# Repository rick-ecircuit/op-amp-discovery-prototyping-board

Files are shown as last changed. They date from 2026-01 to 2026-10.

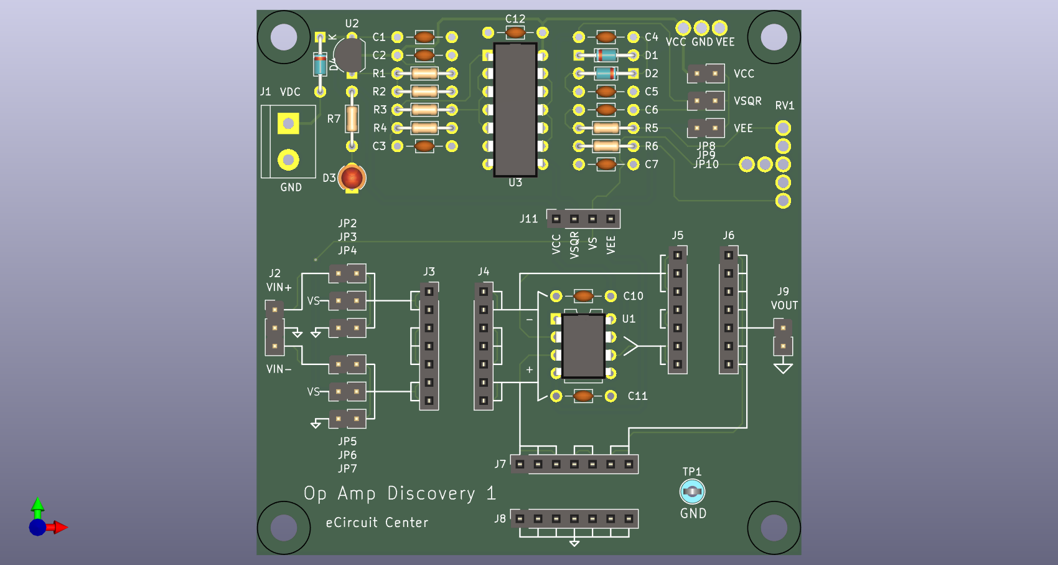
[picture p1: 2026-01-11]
Op_Amp_Discovery_1b/Op_Amp_Discovery_1b.pcb.png

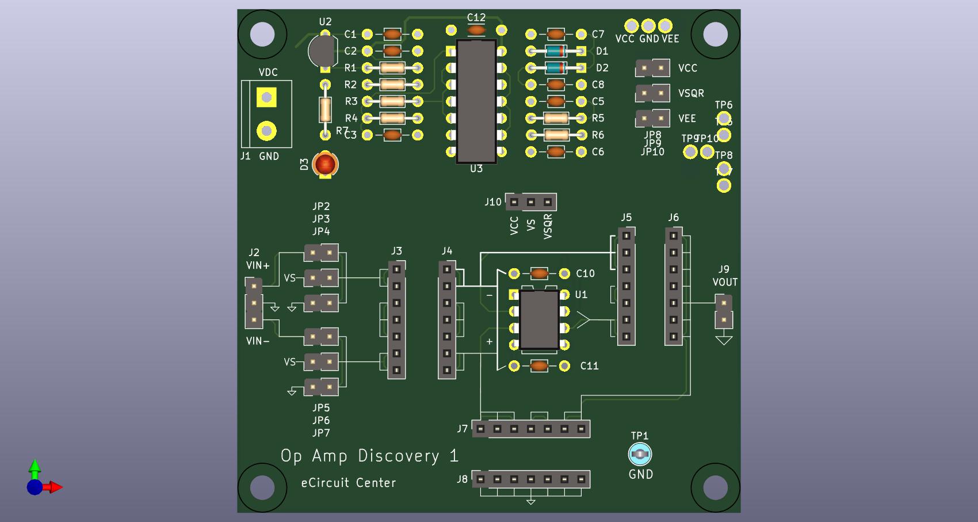
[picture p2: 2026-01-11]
Op_Amp_Discovery_1b/Op_Amp_Discovery_1b.jpg

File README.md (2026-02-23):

# Op Amp Discovery Board
## Fast & Veratile Prototyping and Experimenter Board
The Op Amp Discovery Board allows students, engineers and DIYers to quickly prototype and experiment with a variety of op amp configurations. Get circuits up and running fast! Serves as a Trainer Board as well as an Evaluation Module.

- Easy-to-use hybrid (solderless breadboard + PCB).
- Explore 20+ classic op amp circuits
- Create your own circuits
- Supply Rails & Signal Source Included on-board

Hands-on trainer boosts understanding and intuition!
- Flexible - easily install Rs, Cs or jumpers across any headers.
- Fun problem solving - How-to-build circuit on available component headers?
- Configurable signal - DC, AC, square-wave, level trimpot
- Powered by 9V Battery

Standard breadboards can be frustrating:
- Prone to opens, shorts, intermittent connections
- Confusing, difficult to probe and debug
- Requires expensive, bulky supplies and signal generators

Op Amp Discovery:
- PCB provides solid, versatile connections, power and a signal source.
- Components easily installed on solderless headers.
- Layout arranged like schematic to reinforce learning.
- Minimal cost and PCB space - an affordable & portable learn-anywhere lab.
- Learning possible with a $10 DMM only.

## Users Guide (PDF)
- Quick Start Guide 
- Description, Schematics, BOM
- Proto-Area Schematic, Bonus Sections

## Example Circuits - Guided Learning (PDF)
- Guided examples of classic op amp circuits
- Define It, Design It, Build It, Test & Learn It

## Feedback, Comments, Questions?
Share your thoughts on the [eCircuit Center](https://ecircuitcenter.com/op-amp-discovery/form/feedback1.html) feedback form.

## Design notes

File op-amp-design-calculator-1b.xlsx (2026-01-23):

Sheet: Overview
Overview

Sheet: Non-Inverting
Non-Inverting Amplifier
 |  |  | Enter values
 |  |  | Calc results
Enter circuit
vs | 0.500
R1 | 10000
R2 | 20000
Find gain and output
K | 3.00 | (R1+R2)/R1
vo | 1.500 | vs*K
Find K, R2 given vs, vo, R1
vs | 1.00
vo | 10.00
R1 | 1000
K | 10.00 | Vo/Vs
R2 | 9000 | R1*(K-1)

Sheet: Inverting
Inverting Amplifier
 |  |  | Enter values
 |  |  | Calc results
Enter circuit
vs | 1.000
R1 | 10000
R2 | 20000
Calc gain and output
K | -2.00 | -R2/R1
vo | -2.00 | vs*K
Find R2
vs | 1.000
vo | -10.00
R1 | 1000
K | -10.00 | Vout/Vref
R2 | 10000 | -R1*K

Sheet: Diff Amp
Differential Amplifier
 |  |  | Enter values
 |  |  | Calc results
Enter circuit
R1 | 100000 | ohms
R2 | 100000 | ohms
R3 | 100000 | ohms
R4 | 100000 | ohms
Enter input
Vsp | 5.000 | pos input
Vsn | 4.500 | neg input
Calc Gains Pos and Neg
Kp | 1.000 | R4/(R3+R4) * (R2+R1)/R1
Kn | -1.000 | -R2/R1
Find Output
Vo | 0.500 | (Vsp)*Kp + (Vsn)*Kn

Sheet: Summer
Summing Amplifier
 |  |  | Enter values
 |  |  | Calc results
Enter inputs
vs1 | 5.000 | ohms
R1 | 200000 | ohms
Vs2 | -1.000 | ohms
R2 | 100000 | ohms
Enter feedback
R3 | 100000 | ohms
Calc Gains
K1 | -0.50 | vo/vs1 = -R3/R1
K2 | -1.00 | vo/vs2 = -R3/R2
Calc output due to each input
vo1 | -2.500 | vs1*K1
vo2 | 1.000 | vs2*K2
Sum outputs together
Vo | -1.500 | vo1+vo2

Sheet: Integrator
Integrator
 |  |  | Enter values
 |  |  | Calc results
Enter circuit
Vin | 0.250 | DC input
Δt | 0.000100 | time interval
R1 | 100000
C1 | 1e-10
Find currents in R1,C1
I_R1 | 2.5e-06 | Vin / R1
I_C1 | 2.5e-06 | I_R1
Calc Vout
ΔVout | -2.50 | -1/C1 * I_C1*Δt

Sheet: Differentiator
Differentiator
 |  |  | Enter values
 |  |  | Calc results
Enter input slope
ΔVin | 0.250
Δt | 0.000100
Enter circuit
C1 | 1e-08
R1 | 50000
Find currents in C1,R1
I_C1 | 2.5e-05 | C1*ΔVin/Δt
I_R1 | 2.5e-05 | I_C1 same current as resistor
Calc Vout
Vout | -1.25 | -I_R1*R1
Create Triangle wave from Square wave passed thru Low Pass Filter
Vsqr | 5.00 | amplitude of square wave
fsqr | 5000 | frequency of square wave
Tsqr | 0.000200 | 1/fsqr (period of square wave)
Choose Tau of Low-Pass Filter 5x to 10x longer than Tsqr
Tau | 0.001000 | frequency of square wave
Choose R
R | 1000
Calc C
C | 1e-06 | Tau/R
Calc slope of rising edge "triangle" of filter output
Slope (V/s) | 2500 | Vsqr/2 *1/Tau
Choose time interval
ΔT | 0.000100
Calc voltage change
ΔV | 0.250000 | Slope*ΔT
NOTE: Enter ΔV and ΔT for input slope at top.

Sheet: Sallen-Key LP Fil
Sallen-Key Low-Pass Filter
 |  |  | enter values
 |  |  | calc results
Enter circuit (equal values for R, C and K=1)
R1,2 | 47000
C1,2 | 1e-08
Calculate the cuttoff frequency
fc (-3dB) | 338.6 | 1 / (2 pi R C)
Enter input signal
f (Hz) | 4000.0
Vs | 4.80
Calc approx attenuation of input signal
Katt (ratio) | 11.8 | ≈ f/fc
Katt (dB) | -42.9 | ≈ 2*20*log(f/fc)
vo | 0.034 | ≈ vs*Katt

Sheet: Square Wave Osc
RC Square-Wave Oscilator
 |  |  | enter values
 |  |  | calc results
Enter circuit
R1 | 10000
R2 | 10000
Ro | 47000
Co | 1e-09
Enter output voltage
Vo | 1.80 | LED voltage
Calc feedback ratio
B | 0.500 | Vth = Vo*R1 / (R1+R2)
Find osc frequency and period
fo (Hz) | 9683.396028 | fo = 1 / ( 2*Ro*Co*ln[ (1 - B) /(1 + B) ] )
To (Hz) | 0.0001032695551

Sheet: Wien-Bridge Osc
RC Wien-Bridge Oscilator
 |  |  | enter values
 |  |  | calc results
Enter circuit
R1 | 4700
R2 | 10000
R | 200000 | R3,R4
C | 1e-06 | C3,C4
Calc non-inverting gain: >3 needed for osc
K = vo/vp | 3.13 | k = (R1+R2)/R1
Calc oscillation frequency and period
fo (Hz) | 0.7958 | fo = 1 / (2 pi R C)
To (s) | 1.256637

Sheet: Half-Wave Rect
Precision Rectifier - Inverting Amp
 |  |  | Enter values
 |  |  | Calc results
Enter circuit
vs | 1.000
R1 | 10000
R2 | 20000
Find Vout (for half wave only)
K | -2.00 | -R2/R1
vo | -2.00 | vs*K
Find K, R2 given vs, vo, R1
vs | 1.000
vo | -10.00
R1 | 1000
K | -10.00 | Vout/Vref
R2 | 10000 | -R1*K

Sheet: Cstray
Amplifier with Cstray
 |  |  | Enter values
 |  |  | Calc results
Enter circuit
R1 | 470000
Cstray | 1e-11 | PCB capacitance at U1 neg input
R2 | 470000
CC | 1e-12 | Added compensation Cap
Find time constants of each RC pair
Tau1 | 4.7e-06 | R1*Cstray
Tau2 | 4.7e-07 | R2*CC
Calc CC for matched Tau1 to Tau2
Find CC | 1e-11 | Cstray*R2 / R1
 | Copy this value into CC above.

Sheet: Current Source
Op Amp Current Source
LED Current Drive |  |  | Enter values
 |  |  | Calc results
Enter circuit
Vs | 1.000
Rs | 470
Find Iout
Iout | 0.0021 | Vs/Rs
Enter LED voltage
Vled | 1.800
Calc op amp output voltage
Vu1.out | 2.800 | Vs + Vled

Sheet: Voltage Reg
Voltage Regulator
 |  |  | Enter values
 |  |  | Calc results
Enter circuit
Vs | 1.000
Rload | 1000
Rb | 1000
Enter Q1
Vbe | 0.700
Beta | 100 | current gain Bet = Ic/Ib
Find Vout and Q1 current
Vout | 1.0000 | Vs
Iout = Ie | 0.001000 | Vout/Rload
Ib | 0.000010 | Ie / (Beta+1)
Calc op amp output voltage
Vu1.out | 1.710 | Vout + Vbe + Rb*Ib

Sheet: Remote Sense
Remote Voltage Sense at Rload
 |  |  | Enter values
 |  |  | Calc results
Enter circuit
Vs | 1.000
Rload | 1000
Rwire1 | 100 | resistance of long wire
Rwire2 | 100 | resistance of long wire
Find Iout
Vout | 1.0000 | Vs
Iout | 0.0010 | Vout/Rload
Calc op amp output voltage
Vu1.out | 1.100 | Vout + Iload*Rwire1
NOTE: Negligible voltage across Rwire2 because U1 input bias current relatively small.

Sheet: Twin-T Feedback
Amplifier - Twin-T Feedback
 |  |  | Enter values
 |  |  | Calc results
Enter Circuit
vs | 0.250
R1 | 100000
R2 | 100000
R3 | 10000
R4 | 1000 | Choose R3 10x to 100x less than R2
Calc gain from Vout to Va
Katt = Va/Vout | 0.09 | R4/(R3+R4)
Kmult | 11.00 | 1/Katt (effective mutiplier of R2)
Calc overall gain (approx)
K | -11.00 | -R2*Kmult /R1
Vout | 0.02 | vs*K

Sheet: Thermistor Preamp
Thermistor Preamp
 |  |  | Enter values
 |  |  | Calc results
Enter Circuit
Vcc | 5.000
R1 | 10000
R2 | 10000
Rth | 10000 | Thermistor at 25 deg C
R4 | 10000
Enter thermistor tempco (ΔR/ΔT)
Rtempco | -4.0 | %/C
Calc output at 25C
Vo | 0.000 | Vcc*R4/(Rth+R4)*(R2/R1+1) - Vcc*R2/R1
Calc thermistor at 26C
Rth' | 9600 | Rth*(1 - Rtempco/100)
Calc output at 26C
Vo' | 0.102 | Vcc*R4/(Rth'+R4)*(R2/R1+1) - Vcc*R2/R1
Calc sensitivity - Vo change per degree (25 to 26C)
S = ΔVo/ΔT | 0.102 | (Vo' - Vo ) / 1 deg C
Enter voltage change measured after heat/cold applied to thermistor
ΔVo | 1.200
Calc temperature change
ΔT | 11.8 | ΔVo / S

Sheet: Comparator
Comparator with Hysteresis
Non-Inverting |  |  | Enter values
 |  |  | Calc results
Enter circuit |  | Low Battery (1.5V) Indicator
Vcc | 5.000
R1 | 3300
R2 | 1000
Calc threshold at op amp neg input
Vth | 1.16 | Vcc*R2/(R1+R2)
Enter comparator output hi and lo
Vo_HI | 1.80 | LED Voltage
Vo_LO | -1.80
Calc feedback from Vo to at op amp input (vp) with vo_hi and vo_lo
R3 | 4700
R4 | 100000
K3 | 0.045 | R3/(R3+R4)
Vhys_hi | 0.081 | Vo_hi*K3
Vhys_lo | -0.081 | Vo_lo*K3
Calc equivalent thresholds at vs
K4 | 0.955 | R4/(R3+R4)
Vs_hi | 1.302 | (vth + Vhys_hi)/K4
Vs_lo | 1.133 | (vth - Vhys_lo)/K4
Calc hysteresis
Vhys | 0.169 | Vs_hi - Vs_lo

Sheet: I-to-V Converter
I-to-V Converter
Photodiode Preamp |  |  | Enter values
 |  |  | Calc results
Enter circuit
Is | 1e-06 | Current from photodiode D1 (connected reversed biased.)
R2 | 470000
CC | 1e-10 | Capacitance to keep stable
Calc output
Vout | 0.470 | -Is*R2

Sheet: Single-Supply Amp
Single-Supply AC Amplifier
 |  |  | Enter values
 |  |  | Calc results
Enter signal and gain circuit
Vs | 0.500
C1 | 1e-08
R1 | 10000
R2 | 20000
Enter offset circuit
Vcc | 5.000
R3 | 10000
R4 | 10000
Calc Signal Gain
Ksig | -2.0 | -R2/R1
Calc AC signal output
Vo_AC | -1.000 | Vs*Ksig
Calc DC offset at output
Vo_DC | 2.500 | Vcc*R4/(R3+R4)
Calc cutoff freq fc of C1, R1 input high-pass filter
fo (Hz) | 1591.549431 | fo = 1 / (2*pi*R*C)

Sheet: Capacitive Load
Driving a Capacitive Load
 |  |  | Enter values
 |  |  | Calc results
NOTE: General rules of thumb below.
Enter load
Cload | 1e-06
Enter op amp params
Rout | 40 | output R
fu | 1000000 | unity-gain freq (GBWP)
Enter Isolation resistor so that pole fp << fu
Riso | 100 | typically 20 to 100 ohms
fp (Hz) | 1136.821022 | fp ≈ 1 / (2*pi*(Rout+Riso)*Cload)
Enter Rf ≈ 100 x Riso
Rf | 10000 | typically 1k to 20k
Adjust Cc so that zero fz ≈ fp
Cc | 1.5e-08
fz (Hz) | 1061.032954 | fz ≈ 1 / (2*pi*Rf*Cf)
NOTE: These are rules of thumb only!
Experimentally vary Cc to for acceptable waveform.

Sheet: Signal Source Divider
Signal Source - R-Divider
 |  |  | Enter values
 |  |  | Calc results
Enter signal
Vsqr | 5.00
Enter and R-divider
R5 | 3000
RV1 | 1000
R6 | 1000
Calc output Vs max and min
Vs_max | 2.000 | Vsqr * (RV1+R6) / (R5 + RV1 + R6)
Vs_max | 1.000 | Vsqr * (R6) / (R5 + RV1 + R6)
Calc Input High-Pass Filter
C6 | 1e-07 | Optional: Short if not used
Rtot | 5000 | R5+RV1+R6
fc (Hz) | 318.3098862 | fc = 1 / (2*pi*Rtot*C6)
Calc output Low-Pass Filter
C7 | 1e-09 | Optional: Open if not used
RV1tap (full cw) | 1200 | R5 || (RV1+R6)
fc (Hz) | 132629.1192 | fc = 1 / (2*pi*RV1tap*C7)

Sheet: Linear Regulator
Linear Regulator
 |  |  | Enter values
 |  |  | Calc results
Enter circuit
Vref | 1.250
R1 | 1000
R2 | 3010
Calc output
Vout | 5.01 | (R1+R2)/R1
Find R2
Vref | 1.250
Vout | 5.00
R1 | 1000
K | 4.00 | Vout/Vref
R2 | 3000 | R1*(K-1)

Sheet: RC Inverter Osc
RC Schmitt Oscillator
 |  |  | enter values
 |  |  | calc results
Enter circuit
R | 200000
C | 1e-09
Vcc | 4.80 | Supply
Enter Schmidt trigger thresholds
Vp | 1.700 | positive switching threshold
Vn | 2.780 | negative switching threshold
Calc hi and lo periods
T_hi | 8.566092002e-05 | R*C*ln[ (Vcc - Vn) / (Vcc - Vp) ]
T_lo | 9.836453533e-05 | R*C*ln[ Vn / Vp ]
Calc total period and freq
Ttot | 0.0001840254553 | T_hi + T_lo
fo (Hz) | 5434.030842

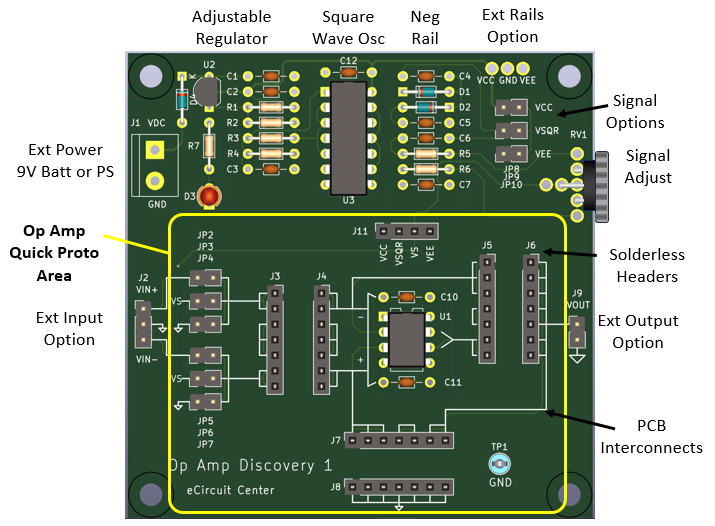
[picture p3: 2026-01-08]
Op-Amp-Discovery-PCB.PNG

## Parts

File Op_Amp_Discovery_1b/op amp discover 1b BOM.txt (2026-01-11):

Reference	Value	Datasheet	Footprint	Qty	DNP
C1,C2	1uF	~	A_Custom_Library:C_Disc_D3.0mm_W1.6mm_P2.50mm_wider_center_dia	2	
C3	1nF	~	A_Custom_Library:C_Disc_D3.0mm_W1.6mm_P2.50mm_wider_center_dia	1	
C4,C5	10uF	~	A_Custom_Library:C_Disc_D3.0mm_W1.6mm_P2.50mm_wider_center_dia	2	
C6,R6	Short	~	A_Custom_Library:C_Disc_D3.0mm_W1.6mm_P2.50mm_wider_center_dia,A_Custom_Library:R_Axial_DIN0204_L3.6mm_D1.6mm_P7.62mm_Horizontal-bigger_hole	2	
C7,R4	Open	~	A_Custom_Library:C_Disc_D3.0mm_W1.6mm_P2.50mm_wider_center_dia,A_Custom_Library:R_Axial_DIN0204_L3.6mm_D1.6mm_P7.62mm_Horizontal-bigger_hole	2	
C10,C11,C12	0.1uF	~	A_Custom_Library:C_Disc_D3.0mm_W1.6mm_P2.50mm_wider_center_dia	3	
D1,D2,D4	1N5711	~	A_Custom_Library:D_DO-34_SOD68_P7.62mm_Horizontal	3	
D3	LED	~	LED_THT:LED_D3.0mm	1	
J1	Screw_Terminal_01x02	~	TerminalBlock:TerminalBlock_bornier-2_P5.08mm	1	
J2	Conn_01x03_Pin	~	Connector_PinHeader_2.54mm:PinHeader_1x03_P2.54mm_Vertical	1	
J3,J4,J5,J6,J7,J8	Conn_01x07	~	Connector_PinSocket_2.54mm:PinSocket_1x07_P2.54mm_Vertical	6	
J9	Conn_01x02_Pin	~	Connector_PinHeader_2.54mm:PinHeader_1x02_P2.54mm_Vertical	1	
J11	Conn_01x04	~	Connector_PinSocket_2.54mm:PinSocket_1x04_P2.54mm_Vertical	1	
JP2,JP3,JP4,JP5,JP6,JP7,JP8,JP9,JP10	Jumper_2_Small_Open	~	Connector_PinHeader_2.54mm:PinHeader_1x02_P2.54mm_Vertical	9	
R1,R7	1k	~	A_Custom_Library:R_Axial_DIN0204_L3.6mm_D1.6mm_P7.62mm_Horizontal-bigger_hole	2	
R2	3.01k	~	A_Custom_Library:R_Axial_DIN0204_L3.6mm_D1.6mm_P7.62mm_Horizontal-bigger_hole	1	
R3	200k	~	A_Custom_Library:R_Axial_DIN0204_L3.6mm_D1.6mm_P7.62mm_Horizontal-bigger_hole	1	
R5	3.3k	~	A_Custom_Library:R_Axial_DIN0204_L3.6mm_D1.6mm_P7.62mm_Horizontal-bigger_hole	1	
TP1,TP2,TP3,TP4,TP5,TP6,TP7,TP8,TP9,TP10,TP11	TestPoint	~	A_Custom_Library:TestPoint_THTPad_D2.0mm_Drill1.0mm_bigger,TestPoint:TestPoint_Keystone_5005-5009_Compact	11	
U1	LM741	http://www.ti.com/lit/ds/symlink/lm741.pdf	Package_DIP:DIP-8_W7.62mm	1	
U2	LM317L_TO92	http://www.ti.com/lit/ds/snvs775k/snvs775k.pdf	Package_TO_SOT_THT:TO-92_Inline_Wide	1	
U3	74HC14	http://www.ti.com/lit/gpn/sn74HC14	Package_DIP:DIP-14_W7.62mm	1

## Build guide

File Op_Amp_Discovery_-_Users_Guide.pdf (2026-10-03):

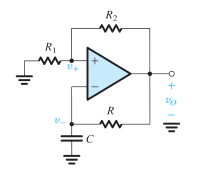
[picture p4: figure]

1 | eCircuit Center | Rev 1c

# Op Amp Discovery

# Fast & Flexible Experimenter and Learning Board

Contents

## 1 Intro

The Op Amp Discovery Board allows students, engineers and DIYers to quickly build and experiment with a variety of op amp configurations. Hands-on learning boosts understanding and intuition!

- Easy-to-use hybrid (solderless breadboard / PCB)
- Explore 20+ classic op amp circuits
- Create your own circuits
- Supply Rails & Signal Source Included on-board

## 2 Fast & Flexible Prototyping

Quickly build and explore many classic op amp circuits with component headers and configurable circuits. Follow self-directed or guided learning.

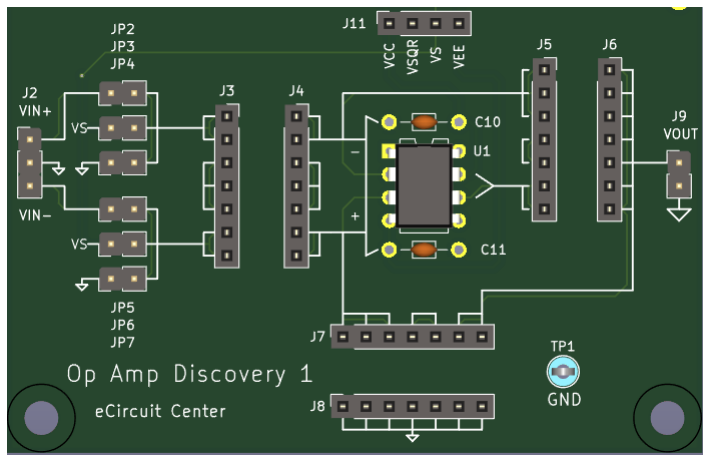
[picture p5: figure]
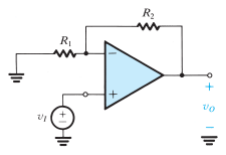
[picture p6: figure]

- Flexible - easily install Rs, Cs or jumpers across any headers.
- Fun problem solving - How-to-build circuit on headers?
- Configurable signal - DC, AC, square-wave, level trimpot

## 3 Problems Solved

Standard breadboards can be frustrating:

- Prone to opens, shorts, intermittent connections
- Confusing, difficult to probe and debug
- Requires expensive, bulky supplies and signal generators

Op Amp Discovery:

- PCB provides solid, versatile connections, power and a signal source.
- Layout arranged like schematic to reinforce learning.
- Minimal cost and PCB space - an affordable & portable learn-anywhere lab.
- Learning possible with a $10 DMM only.

## 4 Overview

The Op Amp Discovery provides essential support circuitry for a stand-alone learning lab. Circuit flexibility allows for custom or more complex setups.

The “Schematic” style of the PCB layout helps build understanding and intuition.

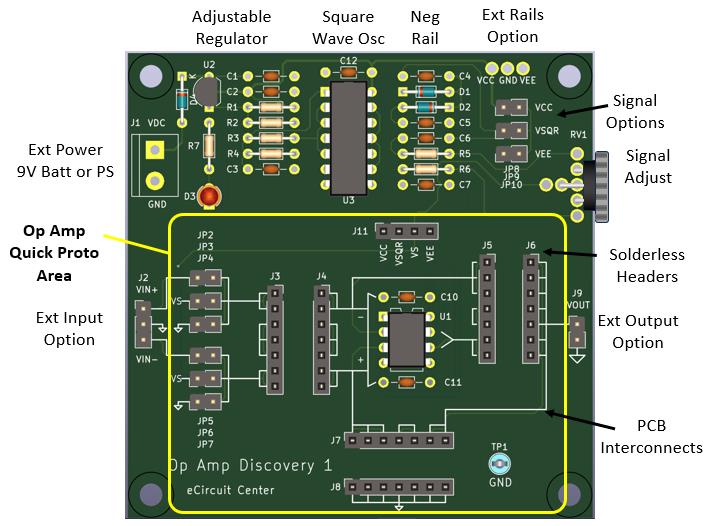
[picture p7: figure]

Overview

- Solderless Headers for easy install of components.
- PCB interconnects for versatile circuit options.
- Op Amp socket for DIP (or SMD on 8-pin header).
- Power from single source (9V battery)

Signal Source

- Scalable Square Wave (0 to 5V)
- Selectable DC or AC coupling.
- Adjustable Amplitude (Trimpot RV1)
- External Input / Outputs (Optional)

Power Rails

- Positive Rail VCC: Adjustable Regulator (5V default)
- Negative Rail VEE: Cap Charge Inverter (-4.5V)
- Solder pads for External Rails option.

## 5 Quick Start Guide

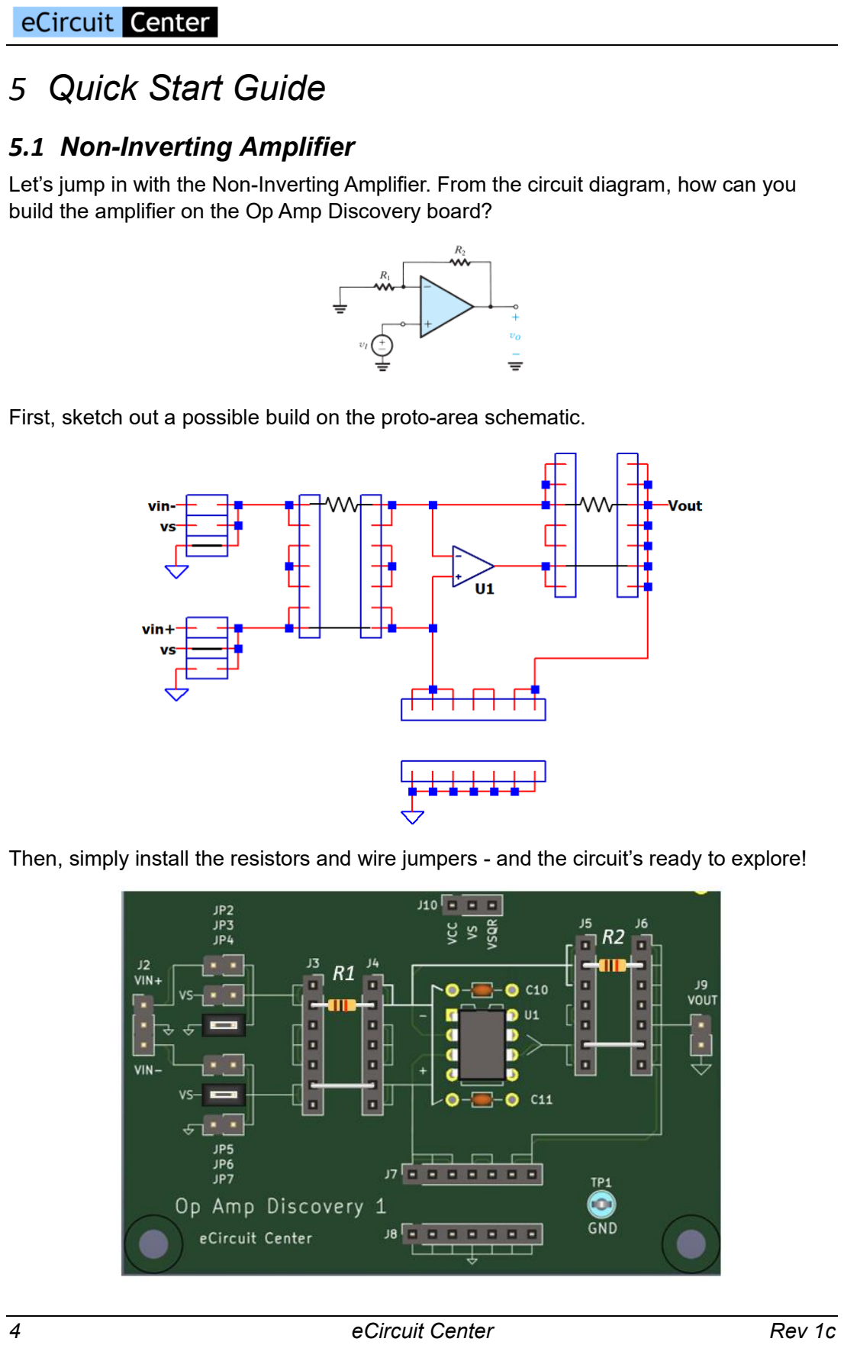
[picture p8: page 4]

### 5.1 Non-Inverting Amplifier

Let’s jump in with the Non-Inverting Amplifier. From the circuit diagram, how can you build the amplifier on the Op Amp Discovery board?

First, sketch out a possible build on the proto-area schematic.

Then, simply install the resistors and wire jumpers - and the circuit’s ready to explore!

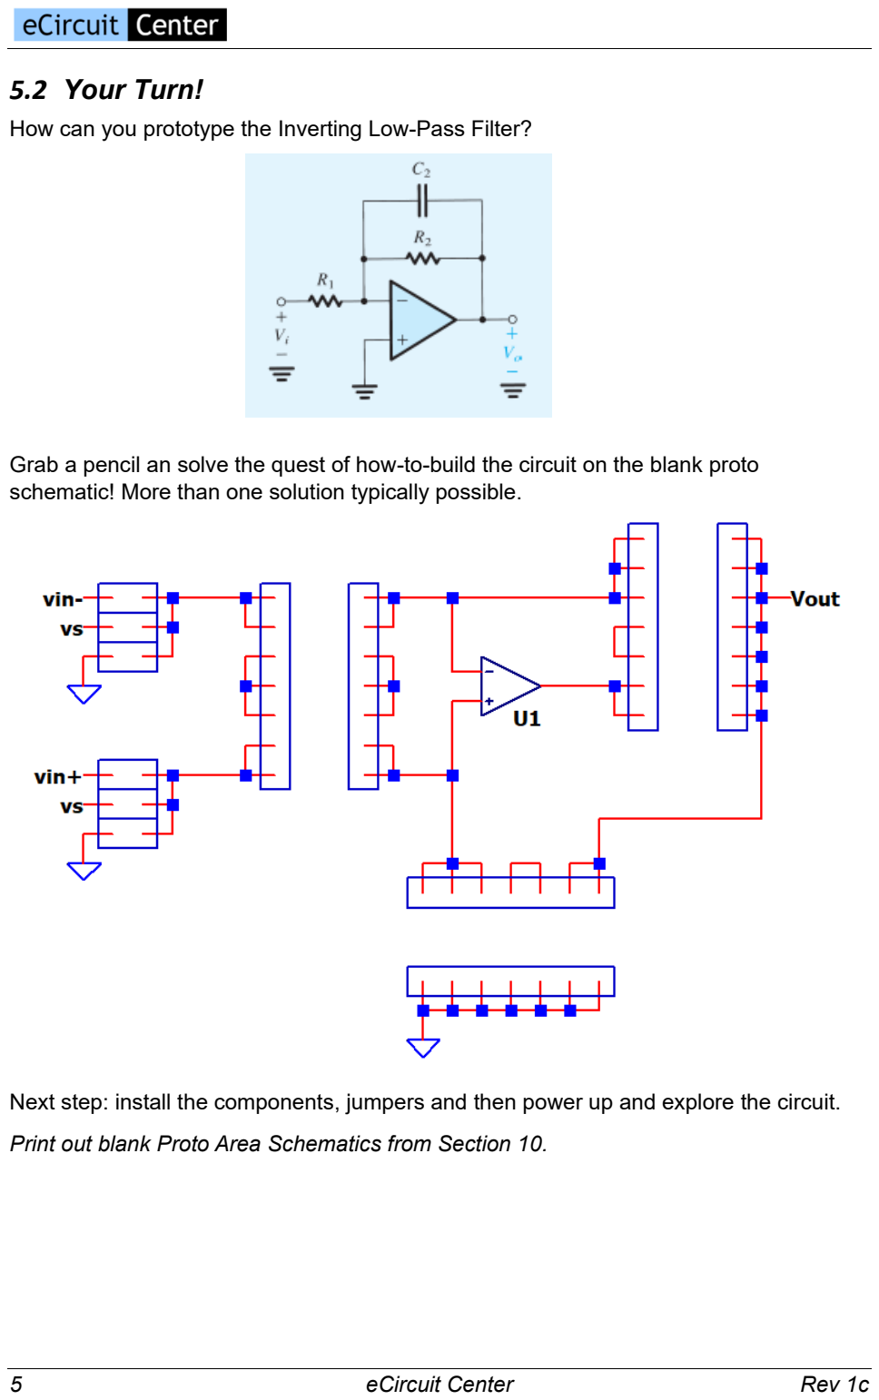
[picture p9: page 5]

### 5.2 Your Turn!

How can you prototype the Inverting Low-Pass Filter?

Grab a pencil an solve the quest of how-to-build the circuit on the blank proto schematic! More than one solution typically possible.

Next step: install the components, jumpers and then power up and explore the circuit.

Print out blank Proto Area Schematics from Section 10.

## 6 Schematic

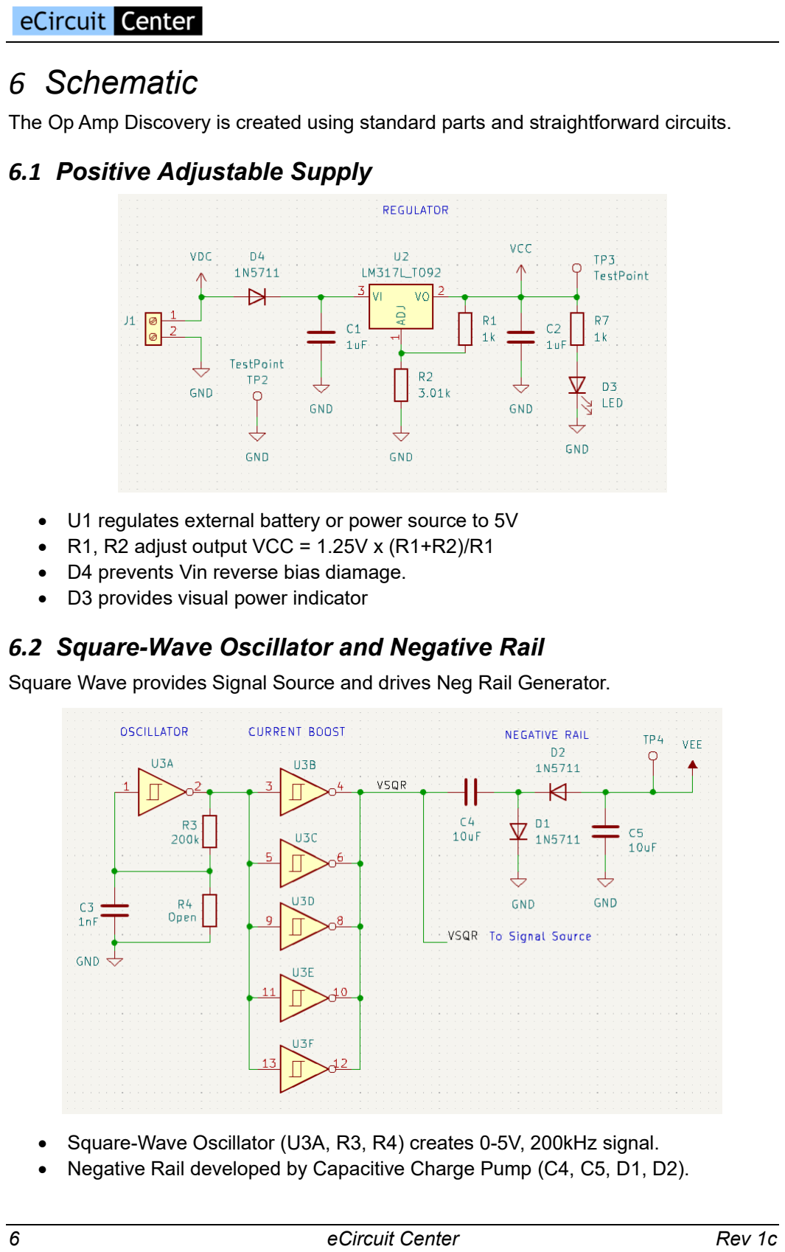
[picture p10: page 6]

The Op Amp Discovery is created using standard parts and straightforward circuits.

### 6.1 Positive Adjustable Supply

- U1 regulates external battery or power source to 5V
- R1, R2 adjust output VCC = 1.25V x (R1+R2)/R1
- D4 prevents Vin reverse bias diamage.
- D3 provides visual power indicator

### 6.2 Square-Wave Oscillator and Negative Rail

Square Wave provides Signal Source and drives Neg Rail Generator.

- Square-Wave Oscillator (U3A, R3, R4) creates 0-5V, 200kHz signal.
- Negative Rail developed by Capacitive Charge Pump (C4, C5, D1, D2).

### 6.3 Signal Source and Scaling

Signal components C6, R5, R6 and C7 easily changed on 4-pin solderless headers for user flexibility.

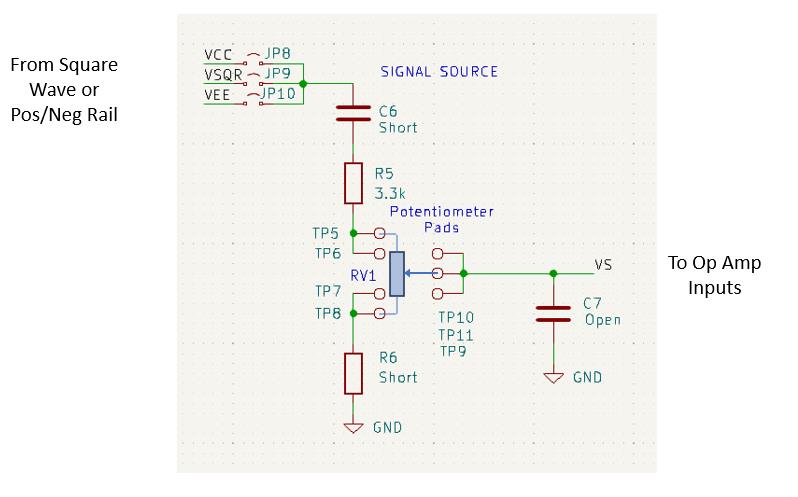
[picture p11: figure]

RV1’s multi-pad PCB layout accommodates a wide variety of Trim Pot types. Flexible signal options.

- Select Signal Source (JP8-10): Square Wave (VSQR) or DC Level (VCC, VEE).
- Choose DC Coupling (C6=short) or AC Coupling (C6=cap)
- Scale signal between 0 and 5V (Resistor Divider R5, RV1 and R6).
- Adjust signal level (RV1)
- Apply Low-Pass Filter (C7 optional).

DC Signal Scaling (R-Divider)

- VS Minimum

VSmin = Vin ∙

R6
R5 + RV1 + R6
- VS Maximum

VSmax = Vin ∙

R6 + RV1
R5 + RV1 + R6

Default Signal Settings

- C6=short, R5=3.01k, RV1=1k, R6=short, C7=open, JP9=ON.
- RV1 adjusts VS for a 0 to 1.25V Square-Wave.

### 6.4 Op Amp Proto Area

Component headers and jumpers create a flexible and intuitive proto lab for exploring op amp circuits.

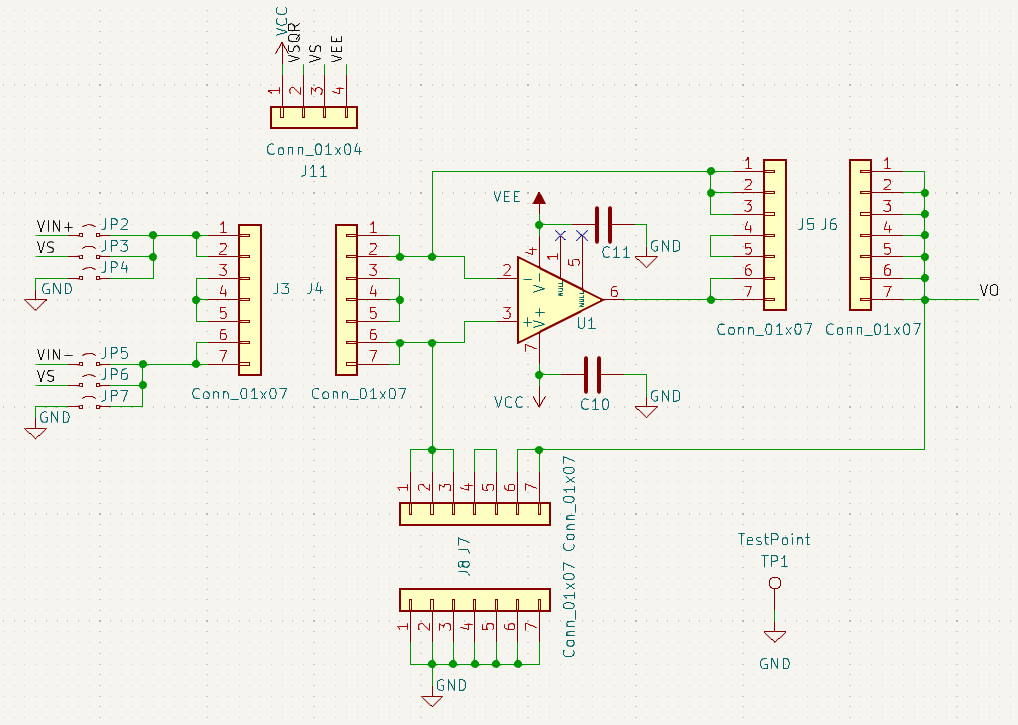
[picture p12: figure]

Prototyping

- Easily install components (Rs, Cs, etc.) across or within any Header Sockets (J3 - J8).

Input Signals

- Select VS, GND or VIN- (ext) to U1 NEG input path (JP2-4).
- Select VS, GND or VIN+ (ext) to U1 POS input path (JP5-7).

Advanced Circuits

- Connect to VCC, VSQR, VS or VEE (J11) for more advanced circuits.
- Install alternate op amps into U1 socket.
- PCB and GND plane allows for wider bandwidths than standard solderless breadboards.

## 7 Op Amp Basic Circuits

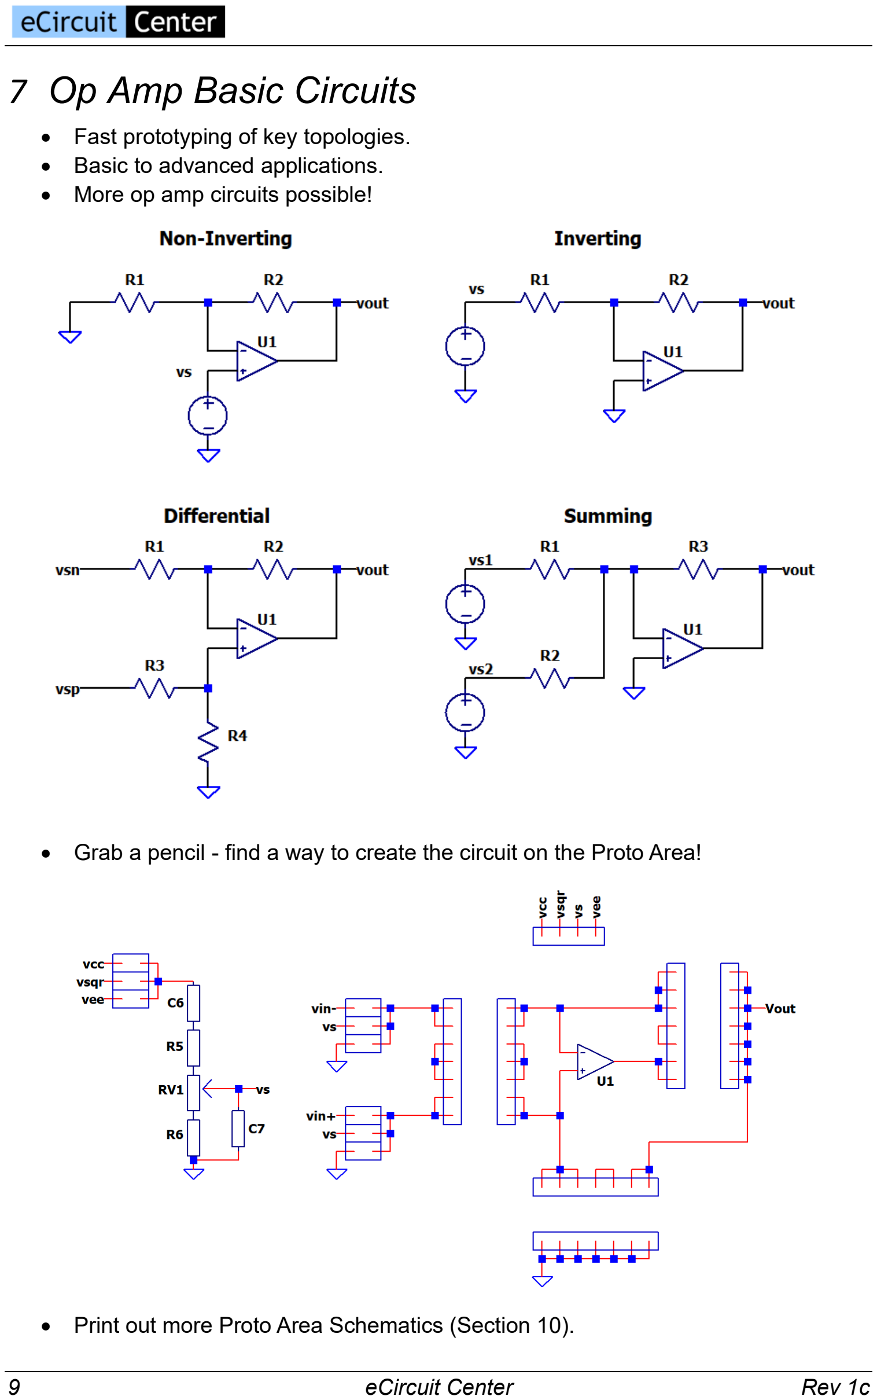
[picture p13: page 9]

- Fast prototyping of key topologies.
- Basic to advanced applications.
- More op amp circuits possible!
- Grab a pencil - find a way to create the circuit on the Proto Area!
- Print out more Proto Area Schematics (Section 10).

## 8 Op Amp Circuits II

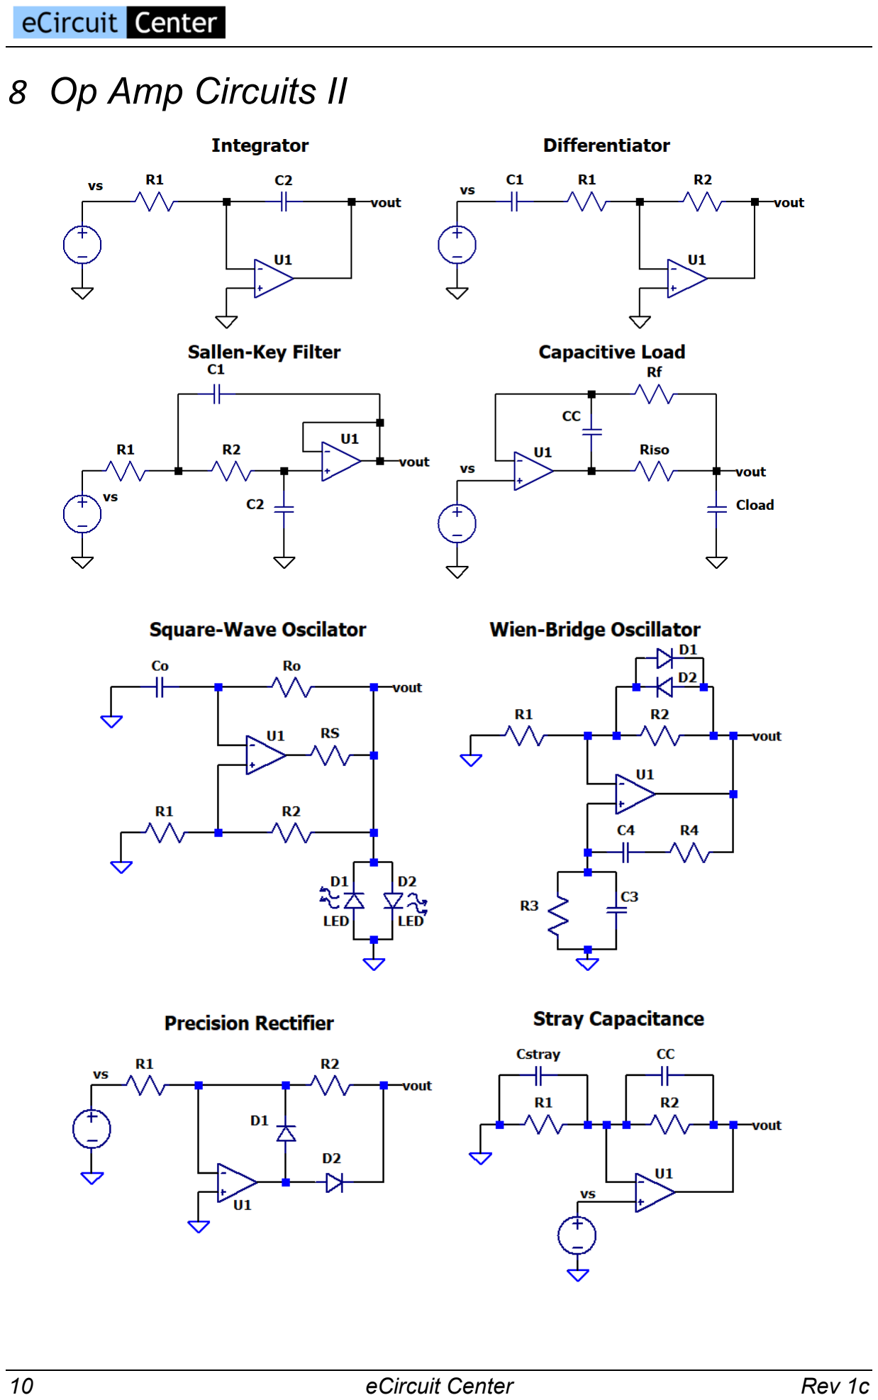
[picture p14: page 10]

## 9 Op Amp Circuits III

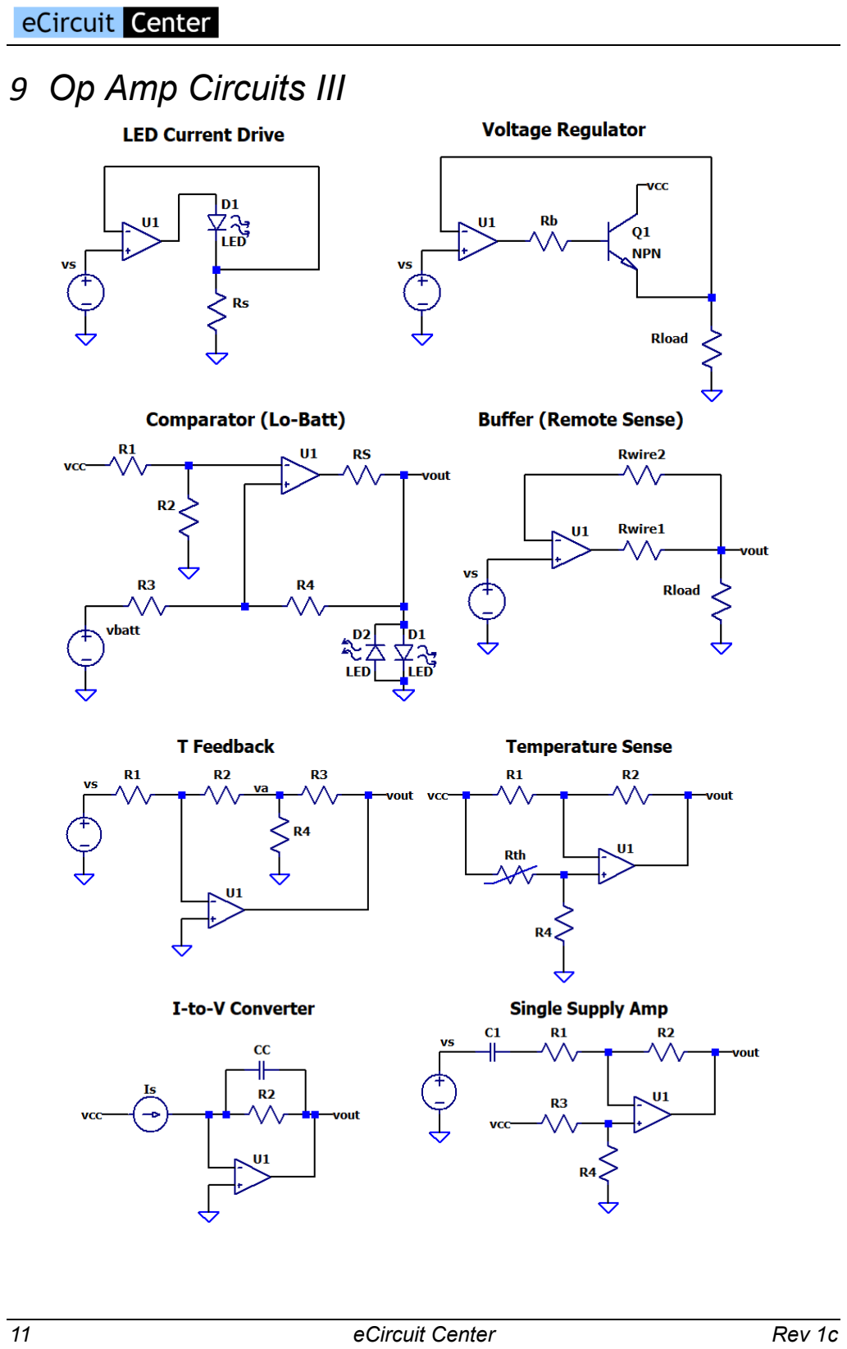
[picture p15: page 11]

## 10 Proto Area Schematics

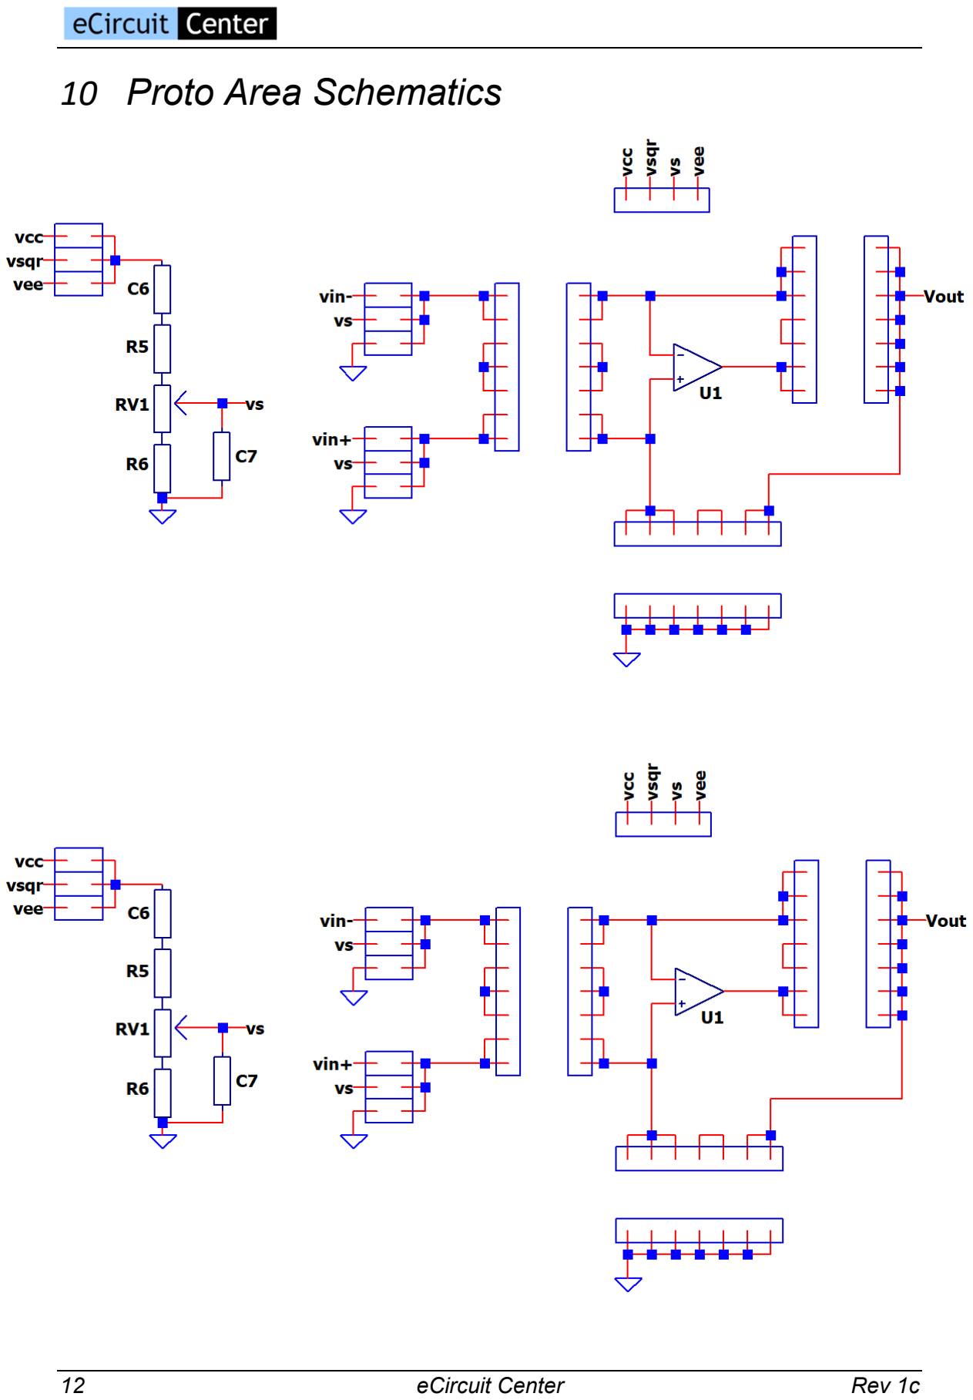
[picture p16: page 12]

## 11 Non-Inverting Amp Walk-Thru

1. Define It – Draw Schematic, choose gains, signal levels, etc.

Let’s amplify a signal by +3. K = Vout/Vs = R1/R2+1 = 3
Choose Vs = 0.5V
2. Design It – Calculate component values, signal levels.

Choose R1 = 10k,
Calc R2 = (K-1) * R1 = 20k

Vout = Vs*K
= 0.5V*3
= 1.5V
3. Build It - Find a way to create it (sketch circuit below, install parts on Discovery Bd.)

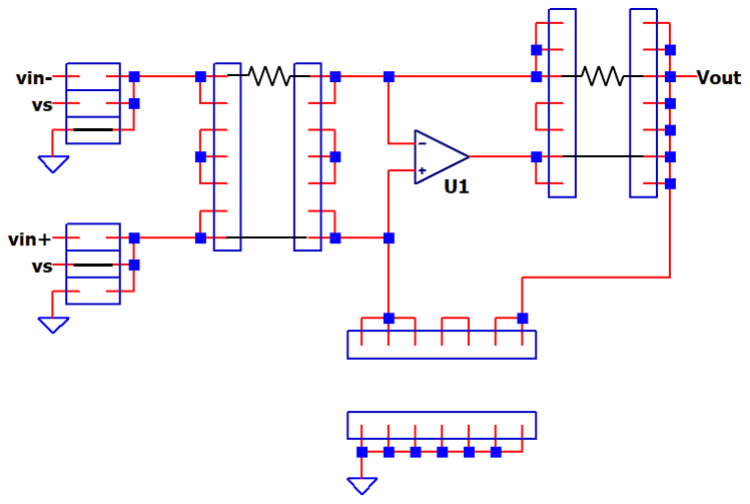
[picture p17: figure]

4. Test & Learn It – Plan setup, make measurements, verify levels, observe, connect to theory.

Power up the circuit (connect 9V Battery).
Connect Probe 1 to VS (Jumper at J3,4).
Connect Probe 2 to VOUT (R2 at Vout side).
Verify a unipolar square wave at VS.

Adjust RV1 for Vs = 0.5V max.
Did Vout achieve the goal?

Move Probe 2 to U1 input- (R1 at U1 side). Does U1.in- follow VS?

What happens if you double R1 or R2?

## 12 Op Amp Discovery Sheets

1. Define It – Draw Schematic, choose gains, signal levels, etc.
2. Design It – Calculate component values, signal levels.
3. Build It - Find a way to create it (sketch circuit below, install parts on Discovery Bd.)
4. Test & Learn It – Plan setup, make measurements, verify levels, observe, connect to theory.

## 13 Parts List

Here’s the default Bill of Materials. Modify and build for your own learning goals.

Reference | Qty | Value | Part # | Comment
C1, C2 | 2 | 1uF | | All caps ceramic, ≥ +25V
C3 | 1 | 1nF
C4, C5 | 2 | 10uF
C6, R6 | 2 | Short | | Short wires or resistor leads.
C7, R4 | 2 | Open
C10, C11, C12 | 3 | 0.1uF
D1, D2, D4 | 3 | Diode | 1N5711
D3 | 1 | LED Yel | LTL-4253 | Any color you prefer.
J1 | 1 | 2-pin Terminal Block screw type | | Optional: Solder 9V Battery Leads or Power Supply Leads directly to pads.
J2 | 1 | 3-pin Header | TSW-103-08-T-S | Optional: for external inputs.
J9 | 1 | 2-pin Header | TSW-102-08-T-S | Optional: for external output.
JP2, JP3, JP4, JP5, JP6, JP7, JP8, JP9, JP10 | 9 | 2-pin Header | TSW-102-08-T-S | 3 Shunts needed typically SNT-100-BK-T
J3, J4, J5, J6, J7, J8 | 6 | 7-pin Socket Header | SSW-107-01-T-S | Sockets for circuit prototyping.
J11, J12, J13 | 3 | 4-pin Socket Header | SSW-104-01-T-S | J12,13 sockets for signal scaling components C6, R5, R6, C7.
R1, R7 | 2 | 1k | | All resistors 1/4W
R2 | 1 | 3.01k
R3 | 1 | 200k
R5 | 1 | 3.01k
RV1 | 1 | 1k trimpot side adjust | 3352W-1-102LF | 5 PCB pads available for various pin styles.
TP1 | 1 | TestPoint | 5011
U1 | 1 | Op Amp | LMC6081IN/NOP8 | Single op amp, rail-to-rail output, +/-7.5V supply max, DIP.
U1 socket | 1 | DIP-8 Socket | 4808-3000-CP
U2 | 1 | Linear Regulator | LM317LZ
U3 | 1 | Hex Inverters Schmidt Trigger | 74HC14APF
U3 socket | 1 | DIP-14 socket | 4814-3000-CP

## 14 Bonus Sections

### 14.1 Revision & Notes

Op Amp Discovery User’s Guide: Rev 1c

I was looking to clear some roadblocks to the hands-on learning of op amps: driving to a limited-hours lab, clearing a work space at home, buying expensive / bulky supplies / generators or struggling with messy circuit wiring on breadboards.

A bit of research and brainstorming led to the idea of the Op Amp Discovery Board - the best of both the solderless breadboard and PCB worlds. A small board with handy component headers, PCB interconnections, supply rails and a square wave generator is where anyone could learn on their kitchen table, in the library or coffee shop.

In a short time, you can get up and running 20+ classic op amp circuits rediscovering the fun and joy of learning about circuits, developing understanding and intuition about their topologies and device behaviors.

Rick Faehnrich

https://www.linkedin.com/in/rick-faehnrich-2671a911/

### 14.2 Excel Op Amp Design Calculator

A handy Design and Analysis Toolkit for 20 Op Amp Circuits. https://ecircuitcenter.com/op-amp-discovery/op-amp-discovery.html

1. Calculate gains, signal levels and frequencies.
2. Modify, customize for your own projects.

### 14.3 Learning Styles

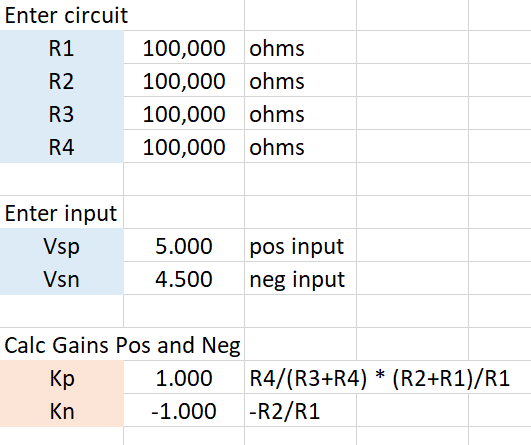
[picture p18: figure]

Dive in any way that propels your learning with Open or Guided learning (or combinations of both).

1. Explore circuits entirely on your own with Self-Directed Learning.
2. Follow Guided Examples of circuits to observe op amp functions and behaviors.
3. Borrow ideas from circuit examples and follow-through on your own.

### 14.4 DMM Only Learning (No Scope)

A Digital Multi-Meter (DMM) serves a low cost alternatve to an oscilloscope. Budget DMMs are available from $10 and up. See the Guided Examples document for tips on getting the most from a DMM.

### 14.5 Circuit Options

External Inputs / Outputs

- Install header pins J2 (input) and J9 (output).
- Install 2-pin shunts at JP2 or JP5.

External Power Supplies

- Un-install U2, R1, C2, R7, C5, D2
- Connect external supplies to PCB plated holes labeled VCC, GND and VEE.

Linear Regulator and Square-Wave Oscillator

- Modify regulator voltage output or oscillator frequency.
- Use the Excel Design Calculator.

### 14.6 KiCAD Software

KiCad is a free and open-source software suite that provides a complete EDA toolset including schematic capture, PCB layout, 3D visualization, and circuit simulation. https://www.kicad.org/

### 14.7 GitHub

The Op Amp Discovery Bd is an open-source project intended to make op amp learning as accessible and affordable as possible. You can down load the documentation and KiCAD project files at https://github.com/rick-ecircuit

### 14.8 Experimenters Parts List

Here’s a suggested selection of parts to explore the circuits.

Reference | Qty | Value
Resistors | 3 each | 100, 1k, 3.3k 10k, 20k, 33k, 39k, 47k 100k, 200k, 330k, 390k, 470k 1M, 4.7M
Capacitors | 2 each | 100pF, 1nF, 10nF, 100nF, 1uF
Seniconductors | 2 each | BJT 2N3904 Diode 1N5711
LEDs | 2 each | RED, GRN
Sensors | 1 each | Thermistor 10k Photodiode
Jumpers | 10 each | Use cut resistor leads

### 14.9 Feedback eCircuitCenter

Feedback on eCircuit Center

✓ How is Op Amp Discovery helpful for you?
✓ What circuits could be added?
✓ What needs clarity?

Send your thoughts on the feedback form at eCircuit Center. https://ecircuitcenter.com/op-amp-discovery/form/feedback1.html

eCircuit Center strives to provide informal, hands-on and fun experiences that lead to a deeper, more intuitive understanding of circuit design and analysis.

### 14.10 Advanced Topics

The Discovery Board allows learning of advanced characteristics and limitations!

- Bandwidth
- Slew-Rate
- Stability
- Voltage / Current Limits
- Linear Regulator and Capacitive Charge Pump
- Heat (Thermal) Management
- RC Oscillators

### 14.11 The Power of Play

- Key to analog success: play, play, play with circuits!
- Analog circuits appear more inviting (and less intimidating) when playing and tinkering.
- Learning and passion grow when you
- Ask “what if” questions
- Play with component values - Predict the outcome!
- Small discoveries and learning fuel motivation and the joy of learning.

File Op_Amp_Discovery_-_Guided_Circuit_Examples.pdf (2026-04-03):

1 | eCircuit Center | Rev 1c

# Op Amp Discovery

# Circuit Examplesfor Guided Learning

### Contents

# 1 Introduction

### Guided Learning is like a buffet table: take as much or as little as you need!

Choose one of three paths to discovery.

1. Follow a walk-through of circuits to observe op amp functions and behaviors.
2. Borrow ideas from circuit examples and follow-through on your own.
3. Explore circuits entirely on your own with self-directed learning.

### The examples are intended to help you

✓ build your circuit discovery and learning skills. ✓ explore op amps in a fun, engaging way.

### Download the User’s Guide and project files at Github

### https://github.com/rick-ecircuit

# 2 Four Key Steps

The topics walk-through an op amp circuit with 4 basic steps.

1. Define It - Draw Schematic, choose gains, signal levels, etc.
2. Design It - Calculate component values, signal levels.

### 3. Build It - Find a way to create it (sketch circuit, install parts on Discovery Bd.)

4. Test & Learn It - Plan setup, make measurements, verify levels, observe, connect to theory.

# 3 What You’ll Need

### The Op Amp Discovery Bd provides the Quick Proto-Board, Supplies and Signal

Source. You’ll need a few additional items to learn and explore.

### - Oscilloscope - Observing waveforms provides key insight

into how circuits work.

### - Suggested: 2 channels with >1MHz

Bandwidth.

### - Budget Scopes (hand-held or USB type) are

available from $40 to $100.

### - DMM

### - A low-budget alternatve to a scope is a basic Digital Mult-Meter (DMM)

available from $10 and up.

### - Select the DC input source on the Discovery Bd and observe the op amp’s

behavior with the DMM.
- See Section 10 for more info.

### - Paper Pad & Excel Calculator - Let your pencil flow freely onto the paper with schematics, equations and

waveforms.

### - The paper is your sandbox to play with ideas - brainstorm, gain clarity, try

and adjust.
- Get the Excel Design Calculator - Scroll to bottom of page.

### https://ecircuitcenter.com/op-amp-discovery/op-amp-discovery.html

# 4 Op Amp Circuit Collection

### Use the guided examples any way you like!

| ▪ Just follow your interest and curiosity! ▪ No rigid order or method.

### Default Signal Source

| ▪ DC Coupled, Square-Wave, 5kHz ▪ Trimpot adjusts Vs from 0 - 1.2V ▪ Default signal setup (unless noted) • C6 = short • R5 = 3.3k • RV1 = 1k trimpot • R6 = short, C7 = open

## 4.1 Non-Inverting Amplifier

Application Example: Boost a weak signal from a small microphone.

1. Define It – Draw Schematic and choose gains, signal levels, etc.

Let’s amplify a signal by K = +2.

K = Vout/Vs = R2/R1+1 = 2

Choose Vs = 0.5V

2. Design It – Calculate component values and signal levels.

Choose R1 = 10k,
Calc R2 = (K-1) * R1 = 10k

Vout = Vs*K
= 0.5V*2
= 1.0V
3. Build It - Find a way to create it (sketch circuit below, install parts on Discovery Bd.)

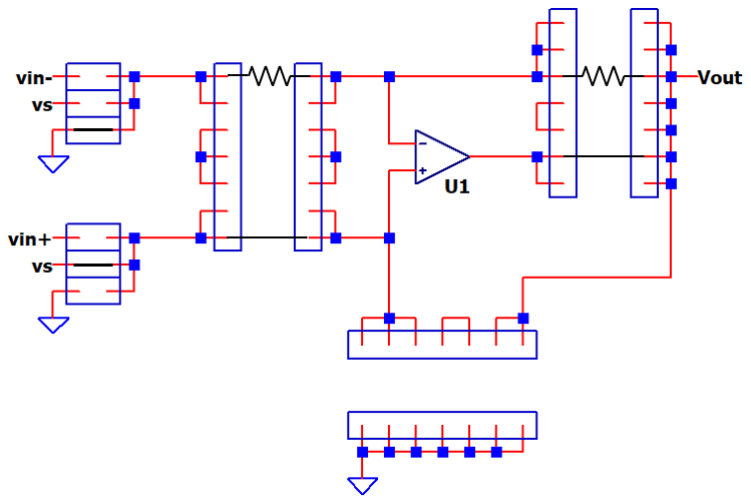
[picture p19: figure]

4. Test & Learn It – Plan setup, make measurements, verify levels, observe, connect to theory.

Power up the circuit (connect 9V Battery).
Connect Probe 1 to VS (Jumper at J3,4).
Connect Probe 2 to VOUT (R2 at Vout side).

Verify a unipolar square wave at VS.

Adjust RV1 for VS = 0.5V peak.
Did Vout achieve the goal?

Move Probe 2 to U1’s negative input (R1 at U1 side). Does U1.in- follow VS?

What happens if you double R1 or R2?

## 4.2 Inverting Amplifier

Application Example: Create a Negative Reference voltage from a Positive one (for a bipolar input ADC).

1. Define It – Draw Schematic, choose gains, signal levels, etc.

Let’s amplify a signal by -1.

Vs = +1V
K = Vout/Vs = -R2/R1 = -1

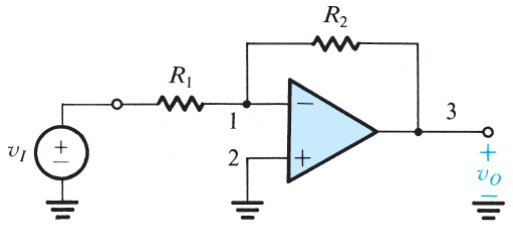
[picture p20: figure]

2. Design It – Calculate component values and signal levels.

Choose R1 = 10k,
Calc R2 = -K * R1 = 10k

Vout = Vs*K
= 1V*-1
= -1V
3. Build It - Find a way to create it (sketch circuit below, install parts on Discovery Bd.)


4. Test & Learn It – Plan setup, make measurements, verify levels, observe, connect to theory.

Power up the circuit (connect 9V Battery).
Connect Probe 1 to VS (R1 at VS side).
Connect Probe 2 to VOUT (R2 at Vout side).

Verify a square wave at VS.

Adjust RV1 for Vs = 1V peak.
Did Vout achieve the goal?

Move Probe 2 to U1’s neg input (R1 at U1 side). Does U1.in- follow GND (0V)?

What happens if you double R1 or R2?

## 4.3 Summing Amplifier

Application Example: Mix together signals from 2 audio channels into a single channel.

1. Define It – Draw schematic, choose gains, signal levels, etc.

What happens when a DC signal (Vcc) is summed with a Square Wave (VS)?

V1 = Vcc = +5VDC
K1 = Vout / Vcc = -R3/R1 = -1/10

V2 = Vsqr = 0 to +1V (Sqr Wave) K2 = Vout / Vsqr = -R3/R2 = -1

2. Design It – Calculate component values and signal levels.

Choose R3 = 10k
Calc R2 = R3 / -K1 = 100k
Calc R1 = R3 / -K2 = 10k

Vout = Vcc*K1 + Vsqr*K2
= Vcc*-0.1 + Vsqr*(-1)
= -0.5 DC level + (0 to -1.0V) Sqr wave Note: RV1 adjusts Square Wave ampitude
3. Build It - Find a way to create it (sketch circuit below, install parts on Discovery Bd.)

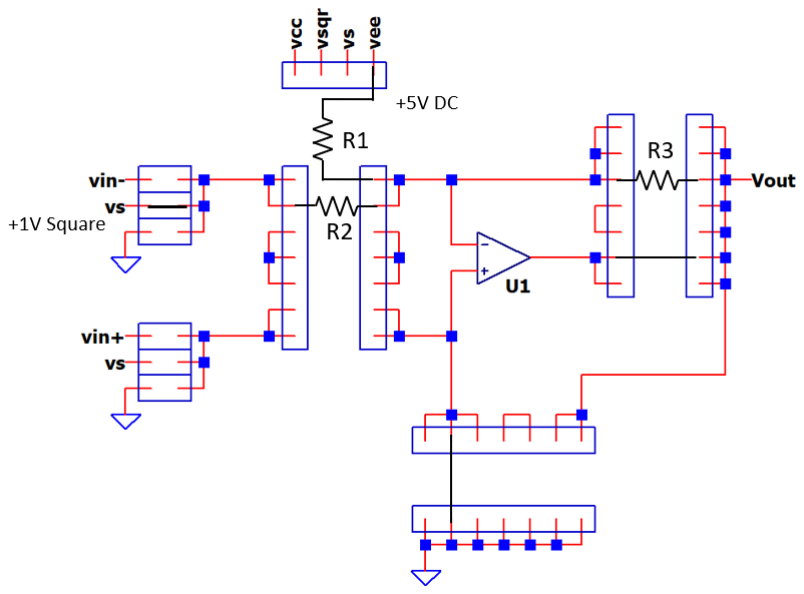
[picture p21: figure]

4. Test & Learn It – Plan setup, make measurements, verify levels, observe, connect to theory.

Power up the circuit (connect 9V Battery).
Connect Probe 1 to VS (R1 at VS side).
Connect Probe 2 to VOUT (R3 at Vout side).

Adjust RV1 for VS=0V peak.
Slowly adjust RV1 for VS=1V peak.
Does the Square Wave get summed with Vout?

What if R2 were halved or doubled?

## 4.4 Differential Amplifier

Application Example: Extract the temperature voltage from sensor signal riding on top of a bias voltage.

1. Define It – Draw Schematic, choose gains, signal levels, etc.

Can the amp sense the difference between Vsqr = 5V and Vs = 4.5V?

Vin+ = Vsqr = +5V
Vin- = Vs = 4.5V
Vin = (Vsqr - Vs) = 0.5V

K = Vout / Vin = R2/R1 = 1

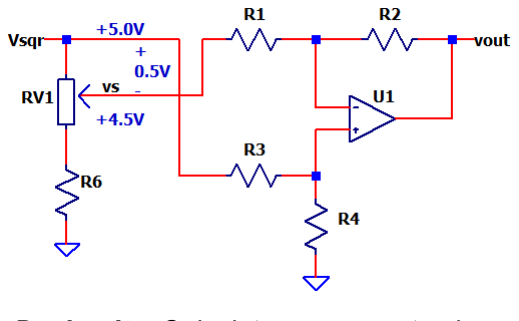
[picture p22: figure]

2. Design It – Calculate component values and signal levels.

Choose R1 = R3 = 10k
Calc R2 = R4 = R1*K = 10k

Vout = (Vin+ - Vin-) * K
= 0.5V * 1
= 0.5V
3. Build It - Find a way to create it (sketch circuit below, install parts on Discovery Bd.)

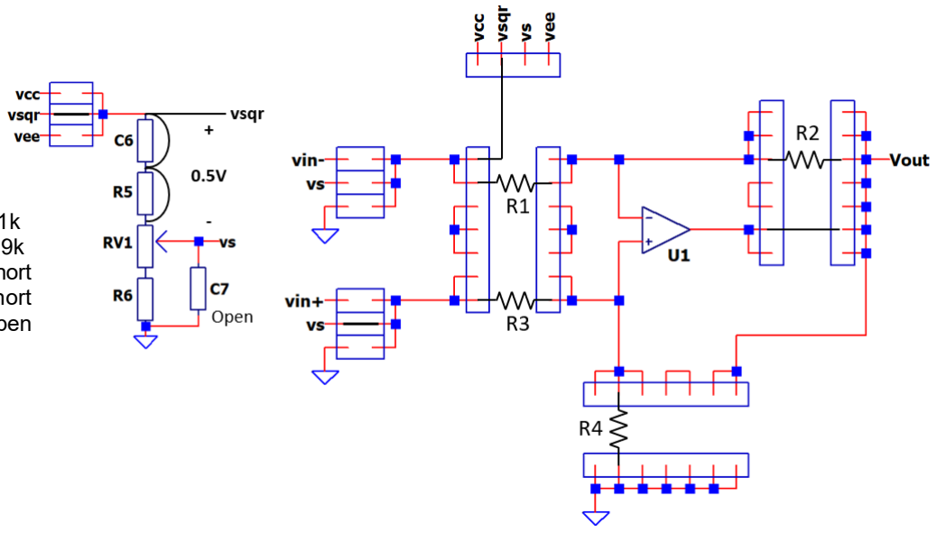
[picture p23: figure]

4. Test & Learn It – Plan setup, make measurements, verify levels, observe, connect to theory.

Power up the circuit (connect 9V Battery).
Connect Probe 1 to VS (R3 at Vs side).
Connect Probe 2 to VOUT (R2 at Vout side).

Adjust RV1 for Vs = +4.5V.
Vsqr should be +5V.
Does Vout achieve its goal?

What happens if you halve or double R2 and R4?

RV1 = 1k
R6 = 3.9k
R5 = short
C6 = short
C7 = open

## 4.5 Integrator

Application Example: Create a triangle-wave (ramp) as part of a PWM motor drive.

1. Define It – Draw Schematic, choose gains, signal levels, etc.

Can the integrator generate a ramp from a sqaure wave input?

Vs = +/-0.25V (Sqr Wave AC coupled) dT = 100us (Square wave half-cycle)

2. Design It – Calculate component values and signal levels.

Choose Rint = 100k, Cint = 100pF
Choose R2 = 4.7M
(R2 makes finite DC gain, keeps offset low.)

dVout = Vs/(Rint*Cint)*dT
= 2.5V
Vout = +/-1.25V
3. Build It - Find a way to create it (sketch circuit below, install parts on Discovery Bd.)

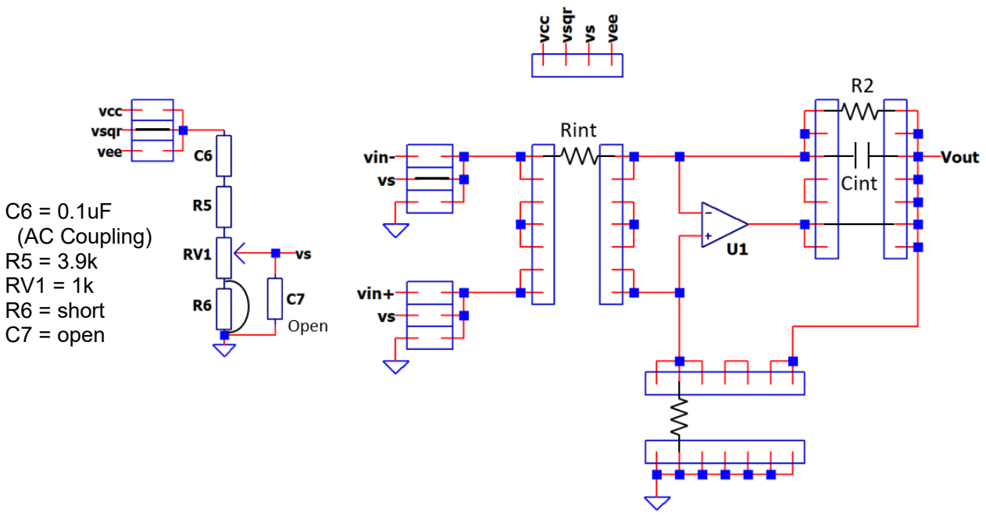
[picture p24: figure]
(AC Coupling) R5 = 3.9k RV1 = 1k R6 = short C7 = open

4. Test & Learn It – Plan setup, make measurements, verify levels, observe, connect to theory.

Power up the circuit (connect 9V Battery).
Connect Probe 1 to VS (Rint at Vs side).
Connect Probe 2 to VOUT (Cint at Vout side).

Adjust RV1 for Vs = +/-0.5V
Does Vout ramp as expected?

What happens if you increase Rint or Cint?

C6 = 0.1uF

## 4.6 Differentiator

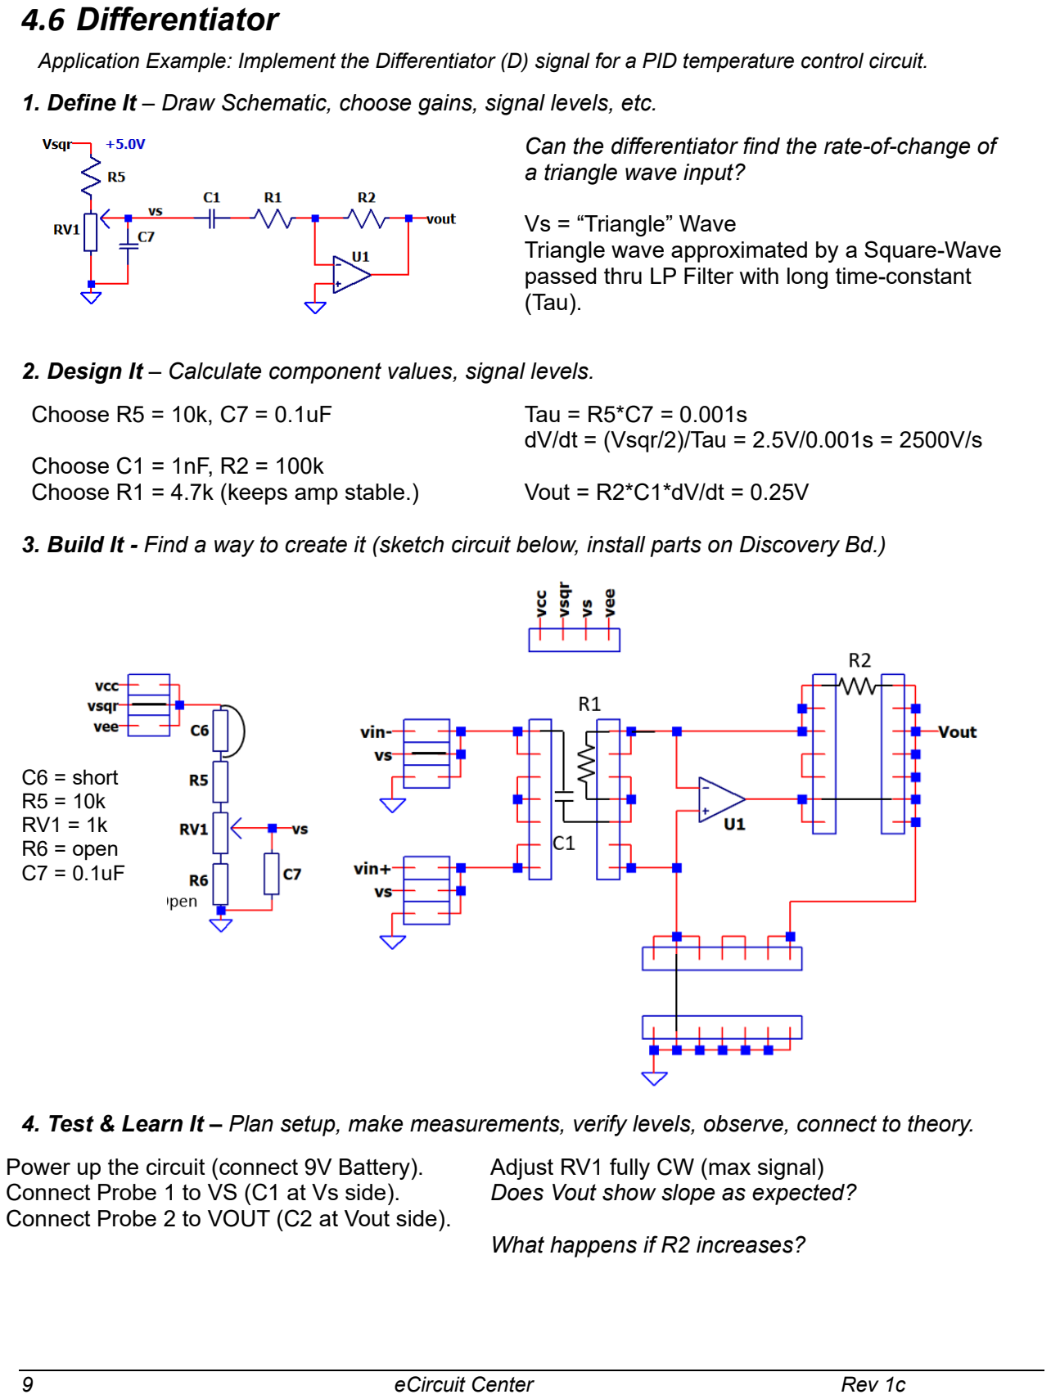
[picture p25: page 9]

Application Example: Implement the Differentiator (D) signal for a PID temperature control circuit.

1. Define It – Draw Schematic, choose gains, signal levels, etc.

Can the differentiator find the rate-of-change of a triangle wave input?

Vs = “Triangle” Wave
Triangle wave approximated by a Square-Wave passed thru LP Filter with long time-constant (Tau).
2. Design It – Calculate component values, signal levels.

Choose R5 = 10k, C7 = 0.1uF

Choose C1 = 1nF, R2 = 100k
Choose R1 = 4.7k (keeps amp stable.)

Tau = R5*C7 = 0.001s
dV/dt = (Vsqr/2)/Tau = 2.5V/0.001s = 2500V/s

Vout = R2*C1*dV/dt = 0.25V

3. Build It - Find a way to create it (sketch circuit below, install parts on Discovery Bd.)
4. Test & Learn It – Plan setup, make measurements, verify levels, observe, connect to theory.

Power up the circuit (connect 9V Battery).
Connect Probe 1 to VS (C1 at Vs side).
Connect Probe 2 to VOUT (C2 at Vout side).

Adjust RV1 fully CW (max signal) Does Vout show slope as expected?

What happens if R2 increases?

C6 = short
R5 = 10k
RV1 = 1k
R6 = open
C7 = 0.1uF

## 4.7 Wien-Bridge Oscillator

Application Example: Generate a sine-wave as a test signal for an audio circuit tester.

1. Define It – Draw Schematic, choose gains, signal levels, etc.

Can you produce a Sine-Wave output with Tper = 300 us?

fo = 1/(2*pi*R*C)

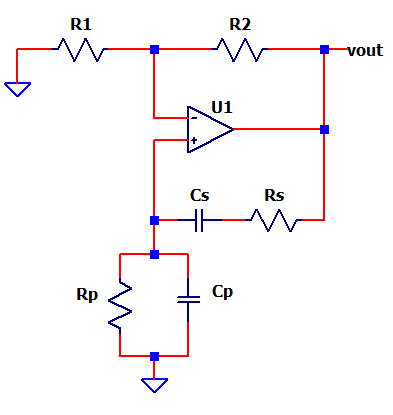
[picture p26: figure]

2. Design It – Calculate component values, signal levels.

Requires gain K > 3 for osc.
Choose R1=4.7k,
Calc R2 = (K-1)*R1 = 9.4k, round up to 10k

Choose C = 1nF, fo = 3.3 kHz Calc R = 1/(2*pi*C*fo)
= 47.8k (use 47k)
3. Build It - Find a way to create it (sketch circuit below, install parts on Discovery Bd.)

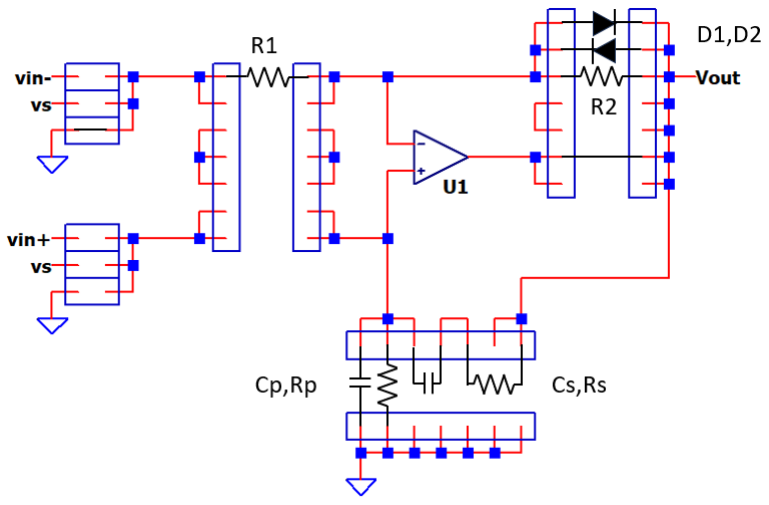
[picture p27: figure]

4. Test & Learn It – Plan setup, make measurements, verify levels, observe, connect to theory.

Power up the circuit (connect 9V Battery).
Connect Probe 1 to VOUT (C2 at Vout side).

Does Vout show the sinewave as designed?

How is Vout related to Vdiode?

## 4.8 V-to-I Converter (LED Drive)

Application Example: Light a front panel LED in proportion to a sensor level (soil moisture for example).

1. Define It – Draw Schematic, choose gains, signal levels, etc.

How can VS be converted into a current through the LED?

Io = Vs / Rs

2. Design It – Calculate component values, signal levels.

Choose Io = 2mA at VS = 1V
Calc RS = VS / Io = 500 ohms
Choose 510 if available

Calc Io = 1V / 510
= 1.98 mA
3. Build It - Find a way to create it (sketch circuit below, install parts on Discovery Bd.)

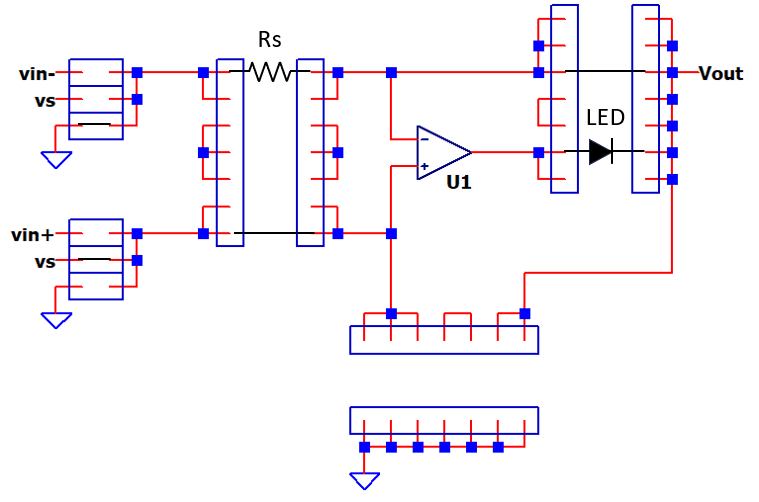
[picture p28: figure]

4. Test & Learn It – Plan setup, make measurements, verify levels, observe, connect to theory.

Power up the circuit (connect 9V Battery).
Connect Probe 1 to VS (Jumper).
Connect Probe 2 to RS (U1 side).

Adjust RV1 for VS = 1V max (Square Wave) Does the RS voltage follow VS?

Move Probe 2 to LED anode (U1.vout).
How much LED voltage is needed above the RS voltage?

What happens to LED current (and brightness) if RS = 1k?

## 4.9 Sallen-Key Low-Pass Filter

Application Example: Convert a square-wave output from a digital tachometer to a DC level.

1. Define It – Draw Schematic, choose gains, signal levels, etc.

How much can the amplitude of a square wave (5Vp-p, 5kHz) be reduced using a 2-pole filter?

fc = 1 / (2*pi*R*C)

H ≈ (fc/fosc)^2

2. Design It – Calculate component values, signal levels.

Choose fc = 333Hz and C1 = 10nF
Calc C1 = 1/(2*pi*10nF*333Hz) = 47.8k
Choose 47k
Calc H ≈ (fc/fosc)^2
≈ 0.0044

Calc expected output with
VS = 5V, fosc = 5k
Vout ≈ VS * (fc/fosc)^2
≈ 22 mVp-p
3. Build It - Find a way to create it (sketch circuit below, install parts on Discovery Bd.)
4. Test & Learn It – Plan setup, make measurements, verify levels, observe, connect to theory.

Power up the circuit (connect 9V Battery).
Connect Probe 1 to R1 (VS side).
Connect Probe 2 to Vout (Jumper).

Adjust RV1 for max 5V Square wave.

How much voltage (peak to peak) appears at Vout?

What is the DC level at Vout and why?

C6 = short
R5 = short
RV1 = 1k
R6 = 3.3k
C7 = open

## 4.10 RC Comparator Oscillator

Application Example: Create a square-wave signal to drive a speaker in a smoke detector.

1. Define It – Draw Schematic, choose gains, signal levels, etc.

What is the oscillation frequency of this Square-Wave output circuit?

fo = 1/(2*Ro*Co ln( (1+B)/(1-B) )

where B = R1/(R1+R2)

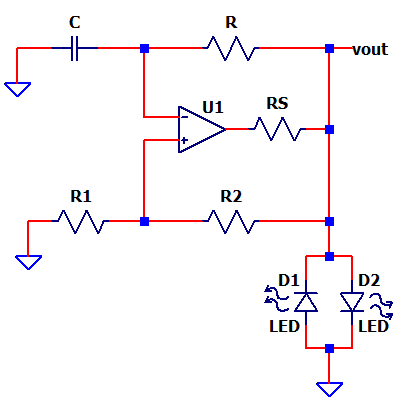
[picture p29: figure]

2. Design It – Calculate component values, signal levels.

Choose handy components
Ro = 100k, Co = 10nF
R1 = 10k, R2 =10k
RS = 1k, LED1,2 = pick two

Calc B = R1/(R1+R2) = 0.5

Calc osc frequency
fo = 1/( 2*100k*10nF*ln((1+0.5)/(1-0.5)) ) = 80 Hz
3. Build It - Find a way to create it (sketch circuit below, install parts on Discovery Bd.)

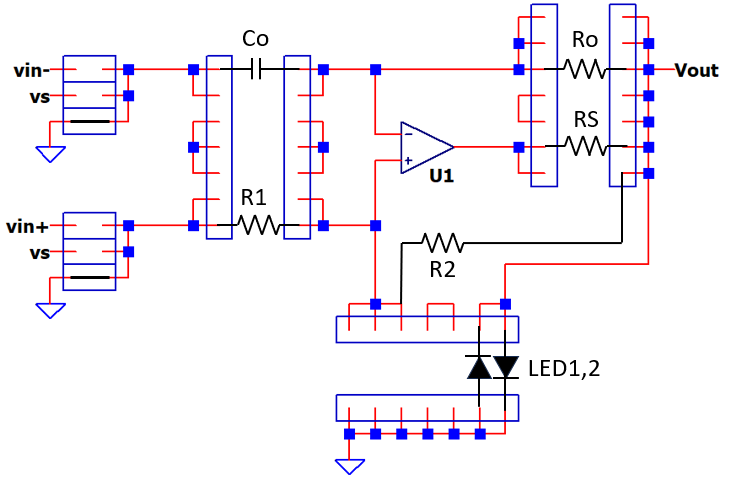
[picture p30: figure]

4. Test & Learn It – Plan setup, make measurements, verify levels, observe, connect to theory.

Power up the circuit (connect 9V Battery).
Connect Probe 1 to VOUT (Ro at Vout side).

Does Vout show the sinewave as designed?

How is Vout related to Vdiode?

## 4.11 Driving a Capacitive Load

Application Example: Drive a sensor signal down a long coaxial cable of high capacitance.

PART 1 - The Overshoot Problem

1. Define It – Draw Schematic, choose gains, signal levels, etc.

What is the overshoot when driving a high capacitive load?

2. Design It – Calculate component values, signal levels.

Choose Cload = 0.1uF or 1uF to observe the
effects of a capacitive load.
3. Build It - Find a way to create it (sketch circuit below, install parts on Discovery Bd.)

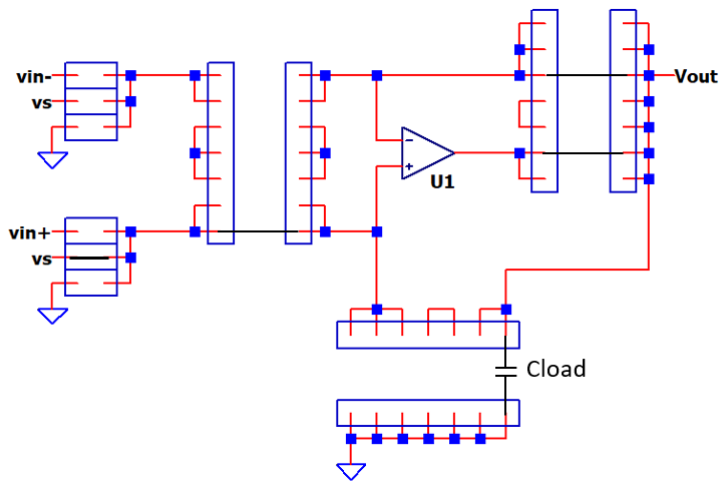
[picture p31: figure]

4. Test & Learn It – Plan setup, make measurements, verify levels, observe, connect to theory.

Power up the circuit (connect 9V Battery).
Connect Probe 1 to VS (Jumper at U1.+).
Connect Probe 2 to Vout (Jumper).

Adjust RV1 for max 1V Square wave.

How much overshoot appears at Vout?

How long Vout take to settle to within +/-0.1V of the final value?

PART 2 - The Overshoot Solution

1. Define It – Draw Schematic, choose gains, signal levels, etc.

Can we reduce the large overshoot when driving a 1uF capacitive load?

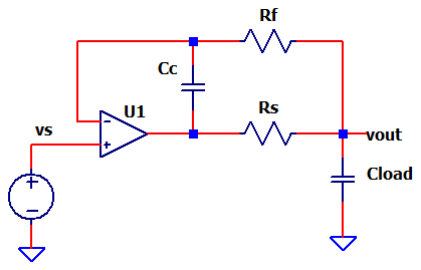
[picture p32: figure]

2. Design It – Calculate component values, signal levels.

Choose Rs = 100 ohms
Choose Rf = Rs*100
= 10k

Solution by experiment!
Adjust CC incrementally: 100pF, 1nF, etc. until the overshoot reduces to an acceptable level.
3. Build It - Find a way to create it (sketch circuit below, install parts on Discovery Bd.)

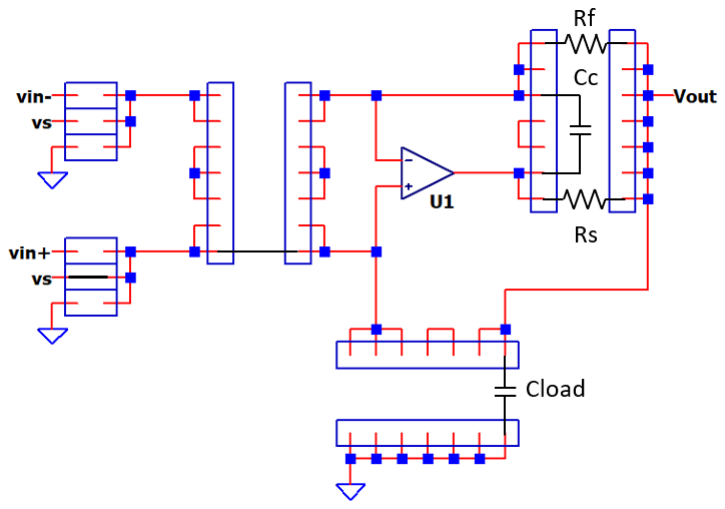
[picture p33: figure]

4. Test & Learn It – Plan setup, make measurements, verify levels, observe, connect to theory.

Power up the circuit (connect 9V Battery).
Connect Probe 1 to VS (Jumper at U1.in+).
Connect Probe 2 to Vout (Rf at Vout)

Adjust RV1 for max 1V Square wave. Install CC = 100pF

How much overshoot appears at Vout? Any overshoot reduction over Part 1?

Install Cc = 1nF, then try 10nF.

What value of Cc reduces overshoot without sacrificing too much settling time?

## 4.12 BJT Regulator

Application Example: Generate a low-voltage supply for motors and relays in a Remote Controlled (RC) car.

1. Define It – Draw Schematic, choose gains, signal levels, etc.

How can a BJT increase the output current drive of an op amp?

K = Vout/Vs = R2/R1+1

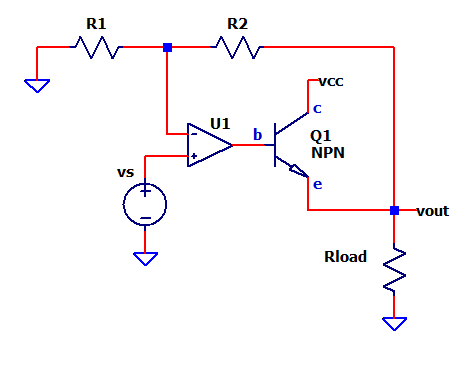
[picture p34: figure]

2. Design It – Calculate component values, signal levels.

Choose Vs = 0.75V, R1 = 10k, K = 2
Rload = 1k

Calc R2 = (K-1)*R1
= 10k
3. Build It - Find a way to create it (sketch circuit below, install parts on Discovery Bd.)

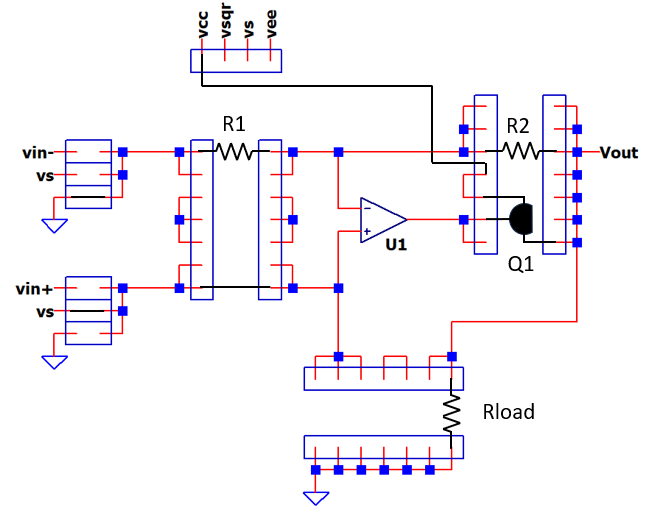
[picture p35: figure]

4. Test & Learn It – Plan setup, make measurements, verify levels, observe, connect to theory.

Power up the circuit (connect 9V Battery).
Connect Probe 1 to Vs (Jumper).
Connect Probe 2 to Vout (R2 at Vout).

Adjust RV1 for VS = 0.75V max
How much current is flowing into Rload?

Move Probe 2 to (Q1.base).
How much voltage does the op amp need to apply to the base to achieve Vout?

Reduce Rload to 100 ohms (increase Iload).
Does Vout hold at 1.5V?
How much voltage at Q1 base is needed now?

## 4.13 Half-Wave Rectifier

Application Example: Measure an Audio Level by rectifying the AC signal (before passing it to a LP filter).

1. Define It – Draw Schematic, choose gains, signal levels, etc.

Let’s pass the positive polarity of a bipolar square wave!

K = Vout / Vs = -R2 / R1 = -2
Vs = +/-0.5V

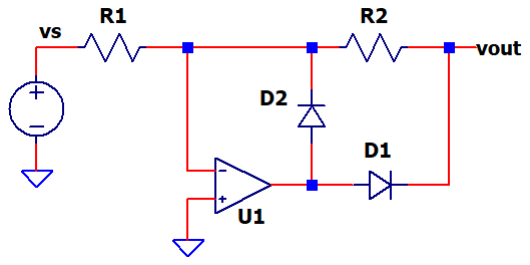
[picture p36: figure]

2. Design It – Calculate component values, signal levels.

Choose R1 = 10k,
Calc R2 = -K * R1 = 20k

Vout = Vs*K
= -0.5V*-2
= +1V
3. Build It - Find a way to create it (sketch circuit below, install parts on Discovery Bd.)

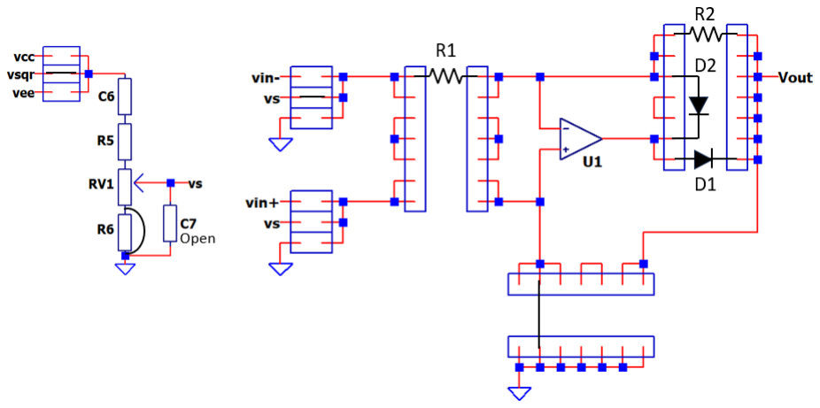
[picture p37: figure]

4. Test & Learn It – Plan setup, make measurements, verify levels, observe, connect to theory.

Power up the circuit (connect 9V Battery).
Connect Probe 1 to VS (R1 at Vs side)
Connect Probe 2 to VOUT (R2 at Vout side).

Adjust RV1 for Vs = +/-0.5V (Square Wave)

Which cycles does the recitifier pass?

What happens if you reverse both diodes D1 and D2?

C6 = 0.1uF
R5 = 3.3k
RV1 = 1k
R6 = short
C7 = open

## 4.14 I-to-V Converter (Photodiode)

Application Example: Measure the light intensity received as part of a Blood Oximeter instrument.

1. Define It – Draw Schematic, choose gains, signal levels, etc.

How can the photodiode current be converted to a voltage?

Vo = Is * -R2

Photodiode: Vishay BV23F

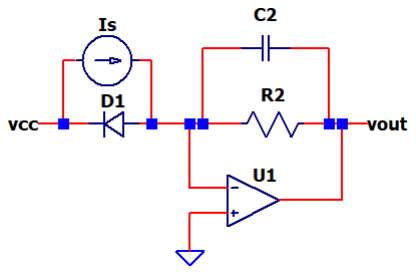
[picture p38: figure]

2. Design It – Calculate component values, signal levels.
Choose R2 = 470k | Ambient light level varies greatly.
3. Build It - Find a way to create it (sketch circuit below, install parts on Discovery Bd.)

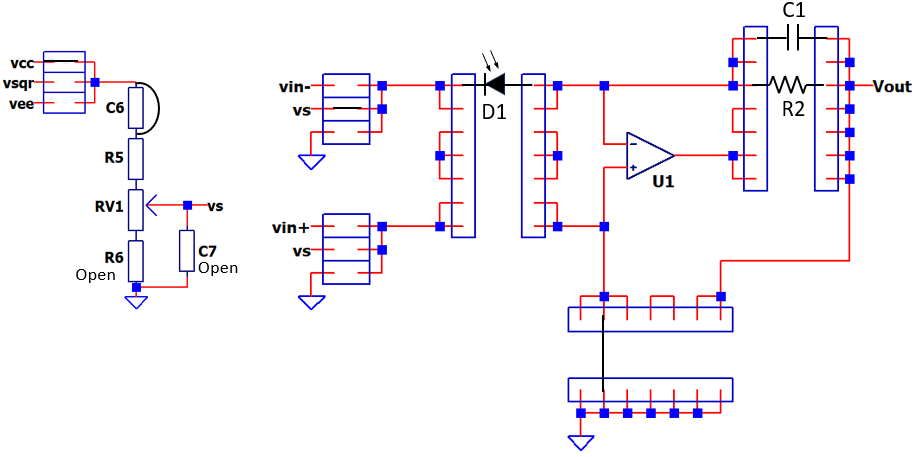
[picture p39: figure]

4. Test & Learn It – Plan setup, make measurements, verify levels, observe, connect to theory.

Power up the circuit (connect 9V Battery).
Connect Probe 1 to Vout (R2 at Vout side)

Does Vs provide +5V reverse bias to the photodiode?

Where is Vout in ambient light?

How much current is flowing out of the photodiode?

What happens when you cover the photodiode with your finger?

## 4.15 Thermistor Preamp

Application Example: Measure the air in-take temperature for an automotive fuel / air mixture control system.

1. Define It – Draw Schematic, choose gains, signal levels, etc.

What is the voltage change at Vout versus a temperature change?

Vout = Vcc * RS/(Rth+RS) * (R2/R1+1) + Vcc*(-R2/R1)

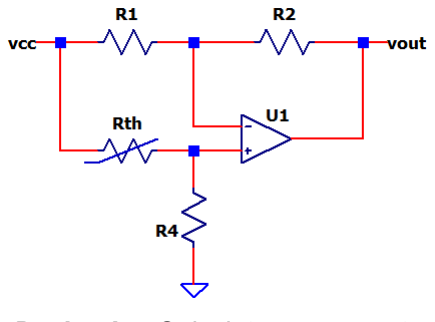
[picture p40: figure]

2. Design It – Calculate component values, signal levels.

Choose Rth = 10k @ 25C
Sensitivity: ΔRth / ΔdT = -4% per C

Choose RS = R1= R2 = 10k

Calc Vout with Rth = 10k @ 25C Vout = 5 * (1/2) * (+2) + 5 *(-1)
= 0V

Calc Vout with Rth = 9.96k @ 26C Vout = 5 * (0.501) * (+2) + 5 *(-1) = +0.1V

ΔVout / ΔT = +0.1V / degC
3. Build It - Find a way to create it (sketch circuit below, install parts on Discovery Bd.)
4. Test & Learn It – Plan setup, make measurements, verify levels, observe, connect to theory.

Power up the circuit (connect 9V Battery).
Connect Probe 2 to Vout (Jumper).

Room Temp: Test Thermistor in free air. (77F or 25C)

Elevated Temp Test: Hold thermistor between thumb and index finger. (90F or 32C)

Temp rise: ΔT = 32 - 25 = 7 deg C.
Voltage rise: ΔVout = 7 deg C * 0.1V/C = 0.7V

What is Vout in free air?

What is Vout with sensor at an elevated temperature

Did ΔVout approximate the temp change by 0.1V/deg C?

# 5 Discovery Sheets

1. Define It – Draw Schematic, choose gains, signal levels, etc.
2. Design It – Calculate component values, signal levels.

Build It - Find a way to create it (sketch circuit below, install parts on Discovery Bd.)

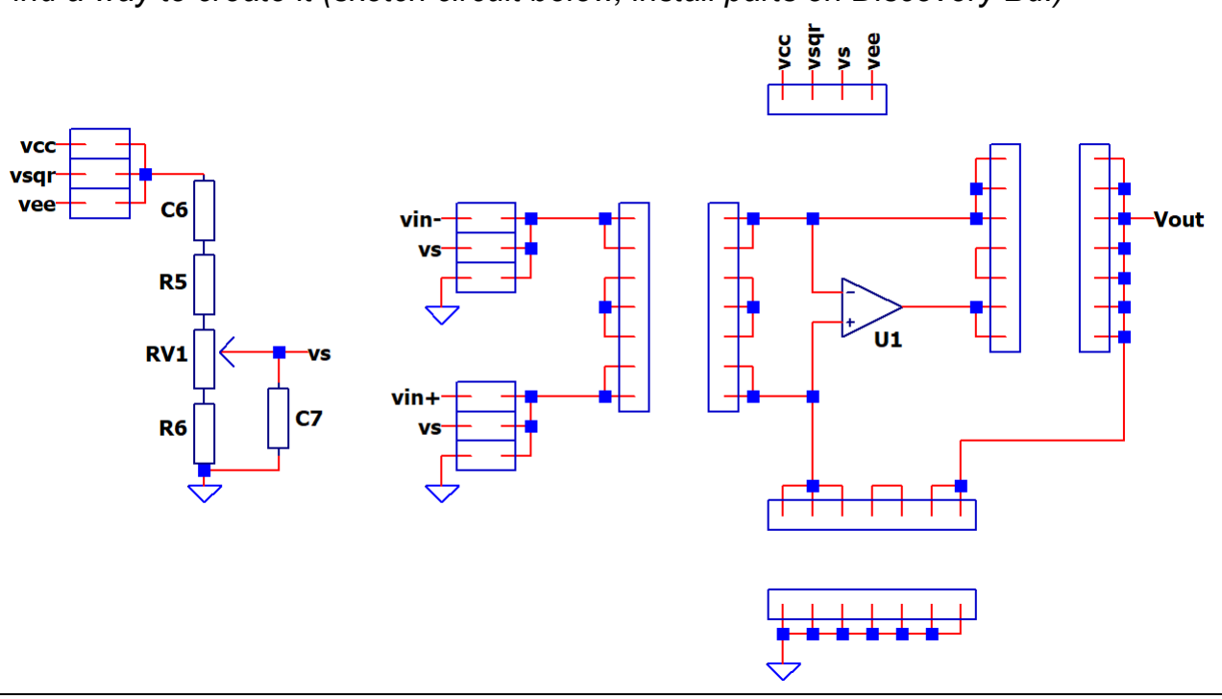
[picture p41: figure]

4. Test & Learn It – Plan setup, make measurements, verify levels, observe, connect to theory.

# - Circuit: ______________________

# 6 Op Amp Learning with a DMM Only

### Learn and explore op amps with only budget Digital Multi-Meter (DMM)!

- Multimeters available for $10 and up.
- Use manual ranging to observe voltage changing.

Select a DC signal for the input to VS.

### - Remove JP1 for Square Wave - Install JP2 for VCC (+5V) or JP3 for VEE (-5V)

- Install short across C6 for DC coupling.

Explore 10+ topologies with just a DMM.

Op Amp Topology | Comment
Non-Inverting Amplfier Inverting Amplifier Summing Amplifier Differential Amplifier Unity-Gain Buffer | Select VCC or VEE as DC source. Vary the input with RV1. Observe Vout with a Volt Meter Function.
V-to-I Converter (LED Drive) | RV1 controls brightness
Wien-Bridge Oscillator RC Bridge Oscillator | Design for low frequency 1 to 5 Hz. Watch LEDs (D1,D2) flash.
Thermistor Preamp | Touch temp sensor, observe Vout change.
I-to-V Converter (Photodiode) | Cover light sensor, observe Vout change.
BJT Regulator | Vary Rload, check Vout stability.

# 7 The Power of Play

### - Key to analog success: play, play, play with circuits!

- Analog circuits appear more inviting (less intimidating) when playing / tinkering.

### - Learning and passion grow when you - Ask “what if” questions - Play with component values Predict outcome!

- Get energized with small discoveries and learning.

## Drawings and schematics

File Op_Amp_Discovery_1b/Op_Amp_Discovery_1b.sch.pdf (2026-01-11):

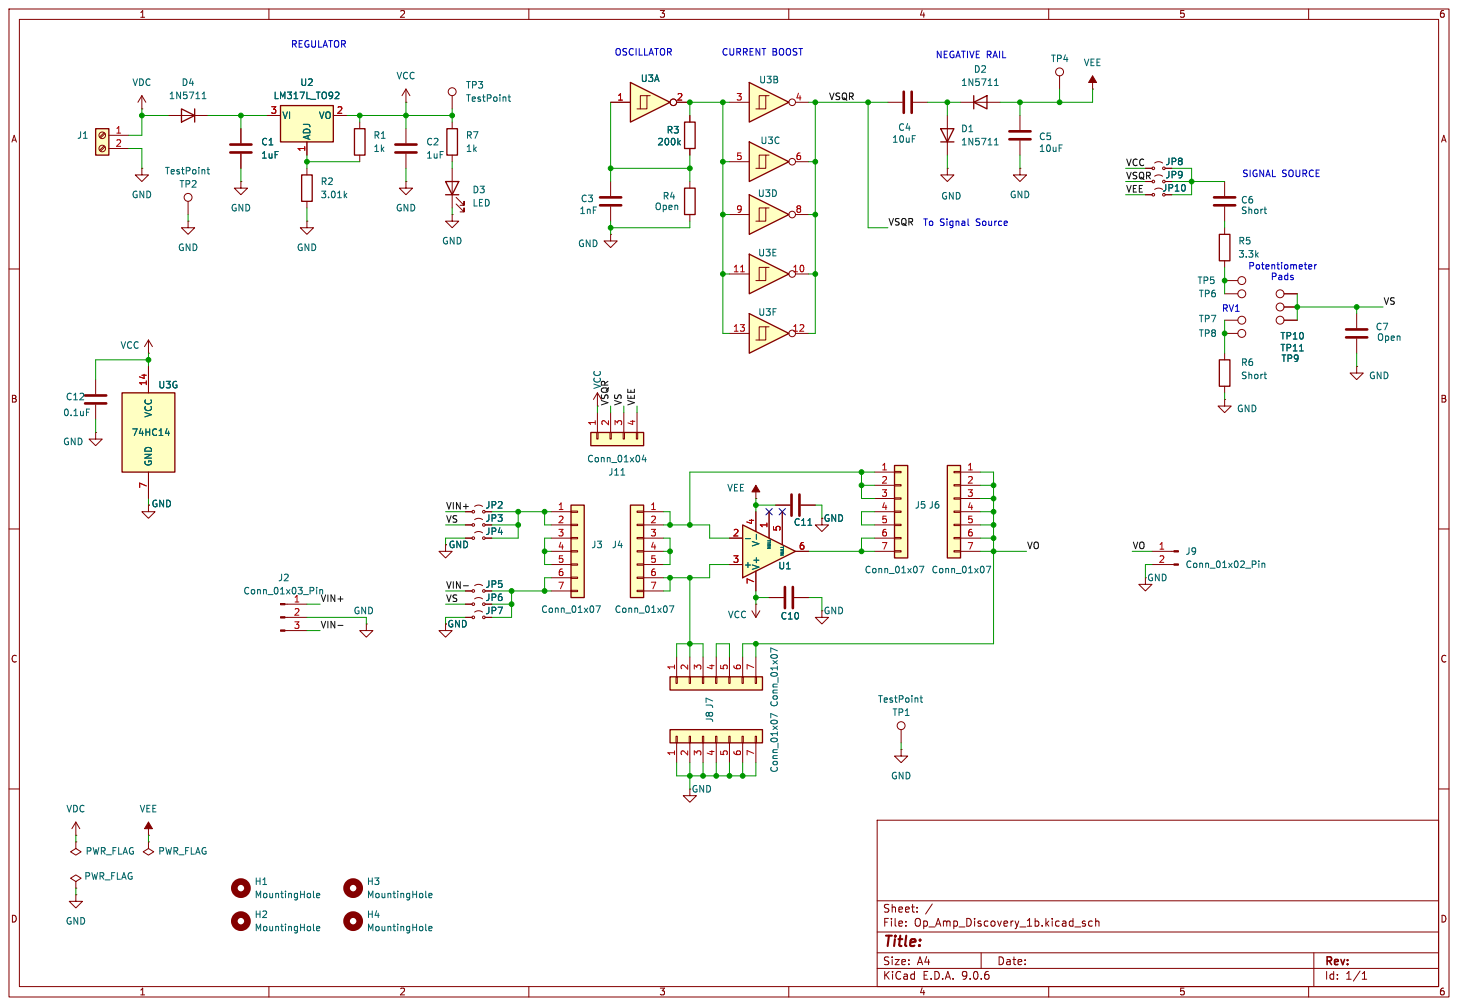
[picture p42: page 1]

J11 Conn_01x04 VCC GND VCC 14 GND

Id: 1/1 Title: File: Op_Amp_Discovery_1b.kicad_sch Sheet: /

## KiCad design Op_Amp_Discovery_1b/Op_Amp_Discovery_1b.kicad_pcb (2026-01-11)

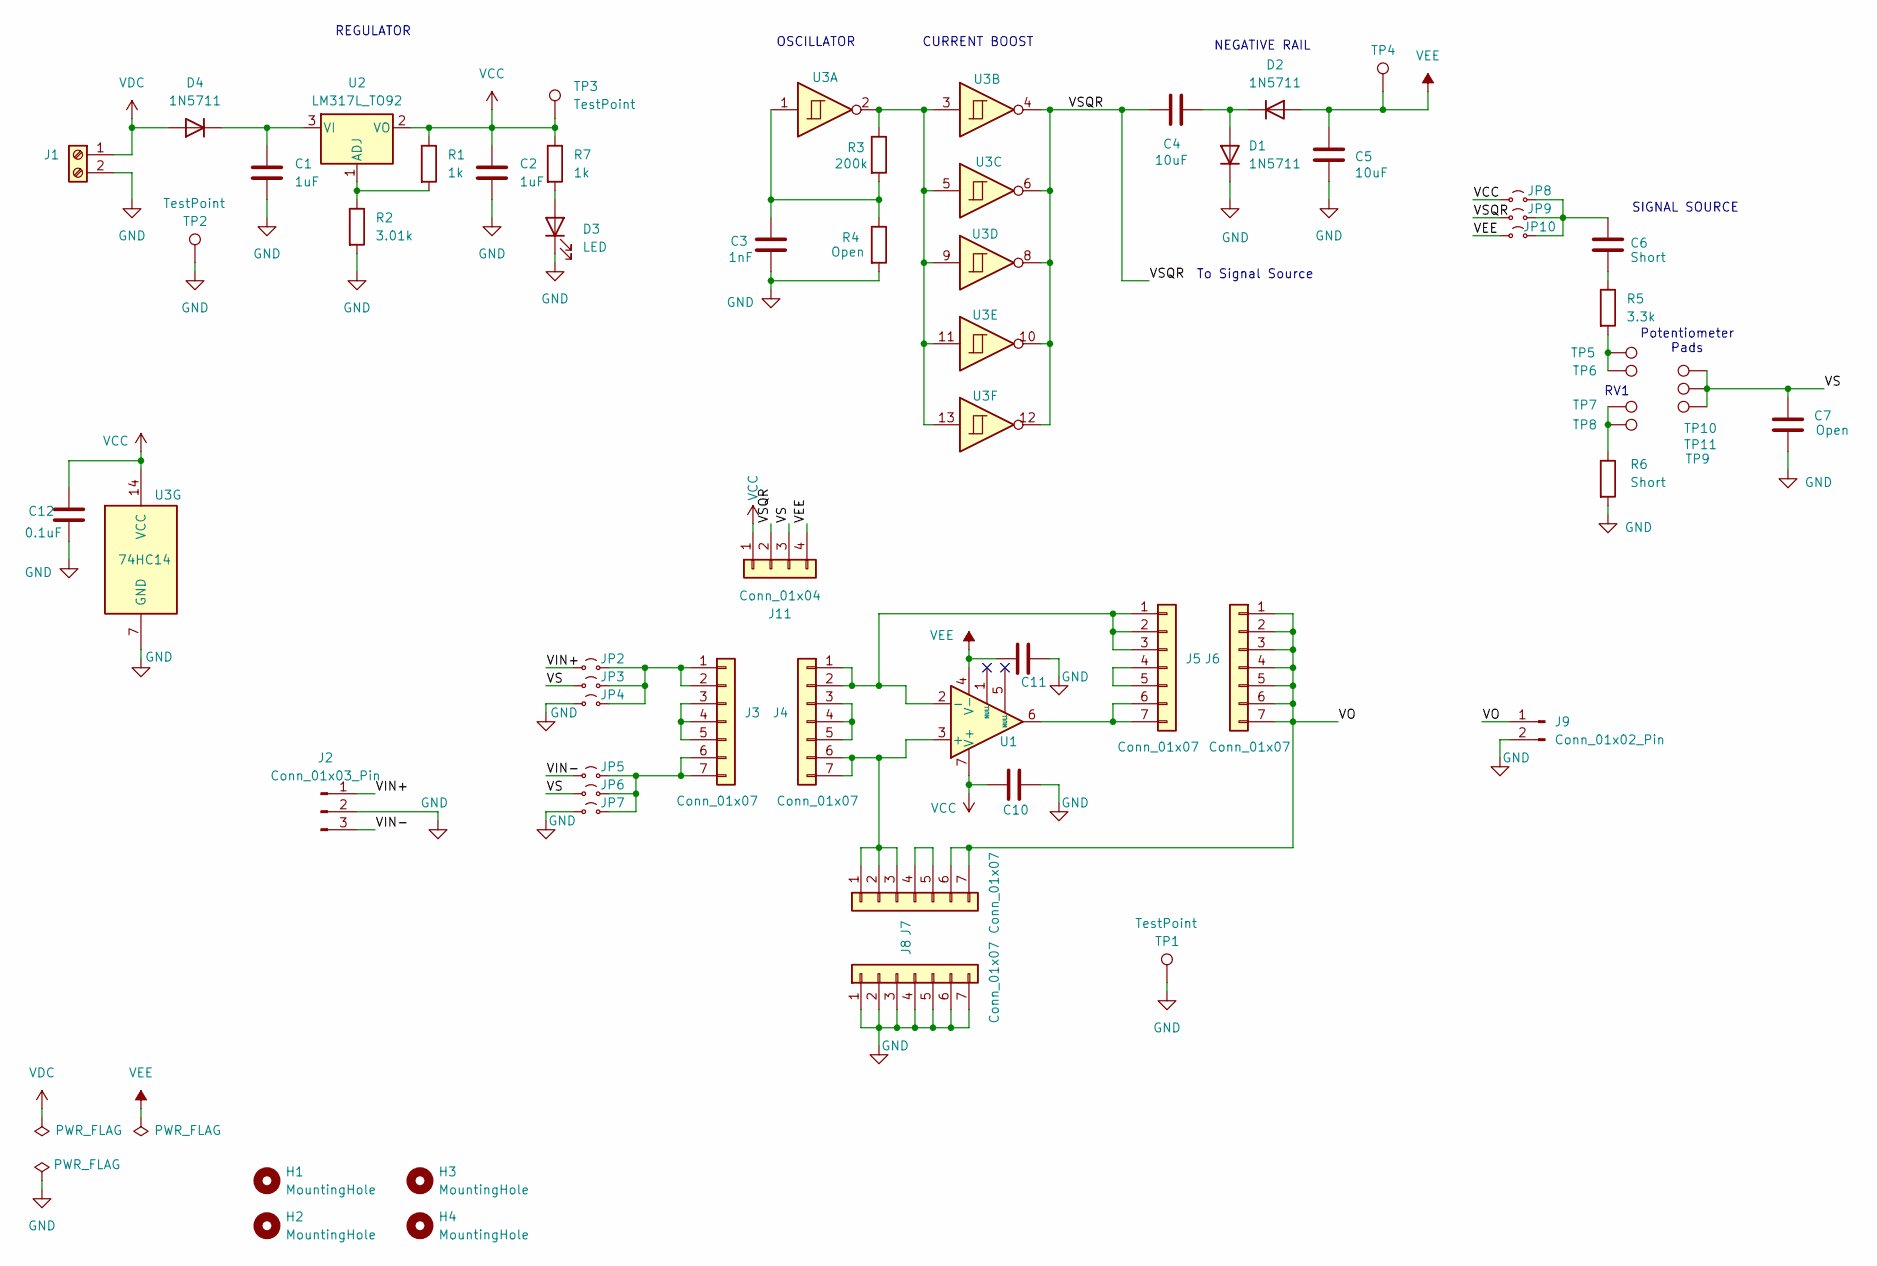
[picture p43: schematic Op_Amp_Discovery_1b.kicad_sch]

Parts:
C1, C2: 1uF; C_Disc_D3.0mm_W1.6mm_P2.50mm_wider_center_dia
C3: 1nF; C_Disc_D3.0mm_W1.6mm_P2.50mm_wider_center_dia
C4, C5: 10uF; C_Disc_D3.0mm_W1.6mm_P2.50mm_wider_center_dia
C6: Short; C_Disc_D3.0mm_W1.6mm_P2.50mm_wider_center_dia
C7: Open; C_Disc_D3.0mm_W1.6mm_P2.50mm_wider_center_dia
C10, C11, C12: 0.1uF; C_Disc_D3.0mm_W1.6mm_P2.50mm_wider_center_dia
D1, D2, D4: 1N5711; D_DO-34_SOD68_P7.62mm_Horizontal
D3: LED; LED_D3.0mm
H1, H2, H3, H4: MountingHole; MountingHole_3.7mm
J1: Screw_Terminal_01x02; TerminalBlock_bornier-2_P5.08mm
J2: Conn_01x03_Pin; PinHeader_1x03_P2.54mm_Vertical
J3, J4, J5, J6, J7, J8: Conn_01x07; PinSocket_1x07_P2.54mm_Vertical
J9: Conn_01x02_Pin; PinHeader_1x02_P2.54mm_Vertical
J11: Conn_01x04; PinSocket_1x04_P2.54mm_Vertical
JP2, JP3, JP4, JP5, JP6, JP7, JP8, JP9, JP10: Jumper_2_Small_Open; PinHeader_1x02_P2.54mm_Vertical
R1, R7: 1k; R_Axial_DIN0204_L3.6mm_D1.6mm_P7.62mm_Horizontal-bigger_hole
R2: 3.01k; R_Axial_DIN0204_L3.6mm_D1.6mm_P7.62mm_Horizontal-bigger_hole
R3: 200k; R_Axial_DIN0204_L3.6mm_D1.6mm_P7.62mm_Horizontal-bigger_hole
R4: Open; R_Axial_DIN0204_L3.6mm_D1.6mm_P7.62mm_Horizontal-bigger_hole
R5: 3.3k; R_Axial_DIN0204_L3.6mm_D1.6mm_P7.62mm_Horizontal-bigger_hole
R6: Short; R_Axial_DIN0204_L3.6mm_D1.6mm_P7.62mm_Horizontal-bigger_hole
TP1: TestPoint; TestPoint_Keystone_5005-5009_Compact
TP2, TP3, TP4, TP5, TP6, TP7, TP8, TP9, TP10, TP11: TestPoint; TestPoint_THTPad_D2.0mm_Drill1.0mm_bigger
U1: LM741; DIP-8_W7.62mm
U2: LM317L_TO92; TO-92_Inline_Wide
U3: 74HC14; DIP-14_W7.62mm

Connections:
/VIN+: J2.1, JP2.1 (A)
/VIN-: J2.3, JP5.1 (A)
/VO: J6.1, J6.2, J6.3, J6.4, J6.5, J6.6, J6.7, J7.6, J7.7, J9.1
/VS: C7.1, J11.3, JP3.1 (A), JP6.1 (A), TP9.1, TP10.1, TP11.1
/VSQR: C4.1, J11.2, JP9.1 (A), U3.4, U3.6, U3.8, U3.10, U3.12
GND: C1.2, C2.2, C3.2, C5.2, C7.2, C10.2, C11.2, C12.2, D1.1 (K), D3.1 (K), J1.2, J2.2, J8.1, J8.2, J8.3, J8.4, J8.5, J8.6, J8.7, J9.2, JP4.1 (A), JP7.1 (A), R2.2, R4.2, R6.2, TP1.1, TP2.1, U3.7 (GND)
unnamed: C3.1, R3.2, R4.1, U3.1
unnamed: C6.2, R5.1
unnamed: C4.2, D1.2 (A), D2.1 (K)
unnamed: D3.2 (A), R7.2
unnamed: C1.1, D4.1 (K), U2.3 (VI)
unnamed: J3.1, J3.2, JP2.2 (B), JP3.2 (B), JP4.2 (B)
unnamed: J3.3, J3.4, J3.5
unnamed: J3.6, J3.7, JP5.2 (B), JP6.2 (B), JP7.2 (B)
unnamed: J4.1, J4.2, J5.1, J5.2, J5.3, U1.2 (-)
unnamed: J4.3, J4.4, J4.5
unnamed: J4.6, J4.7, J7.1, J7.2, J7.3, U1.3 (+)
unnamed: J5.4, J5.5
unnamed: J5.6, J5.7, U1.6
unnamed: J7.4, J7.5
unnamed: C6.1, JP8.2 (B), JP9.2 (B), JP10.2 (B)
unnamed: R3.1, U3.2, U3.3, U3.5, U3.9, U3.11, U3.13
unnamed: R5.2, TP5.1, TP6.1
unnamed: R6.1, TP7.1, TP8.1
unnamed: R1.2, R2.1, U2.1 (ADJ)
VCC: C2.1, C10.1, C12.1, J11.1, JP8.1 (A), R1.1, R7.1, TP3.1, U1.7 (V+), U2.2 (VO), U3.14 (VCC)
VDC: D4.2 (A), J1.1
VEE: C5.1, C11.1, D2.2 (A), J11.4, JP10.1 (A), TP4.1, U1.4 (V-)

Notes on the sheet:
OSCILLATOR
To Signal Source
CURRENT BOOST
NEGATIVE RAIL
Potentiometer Pads
REGULATOR
SIGNAL SOURCE
RV1

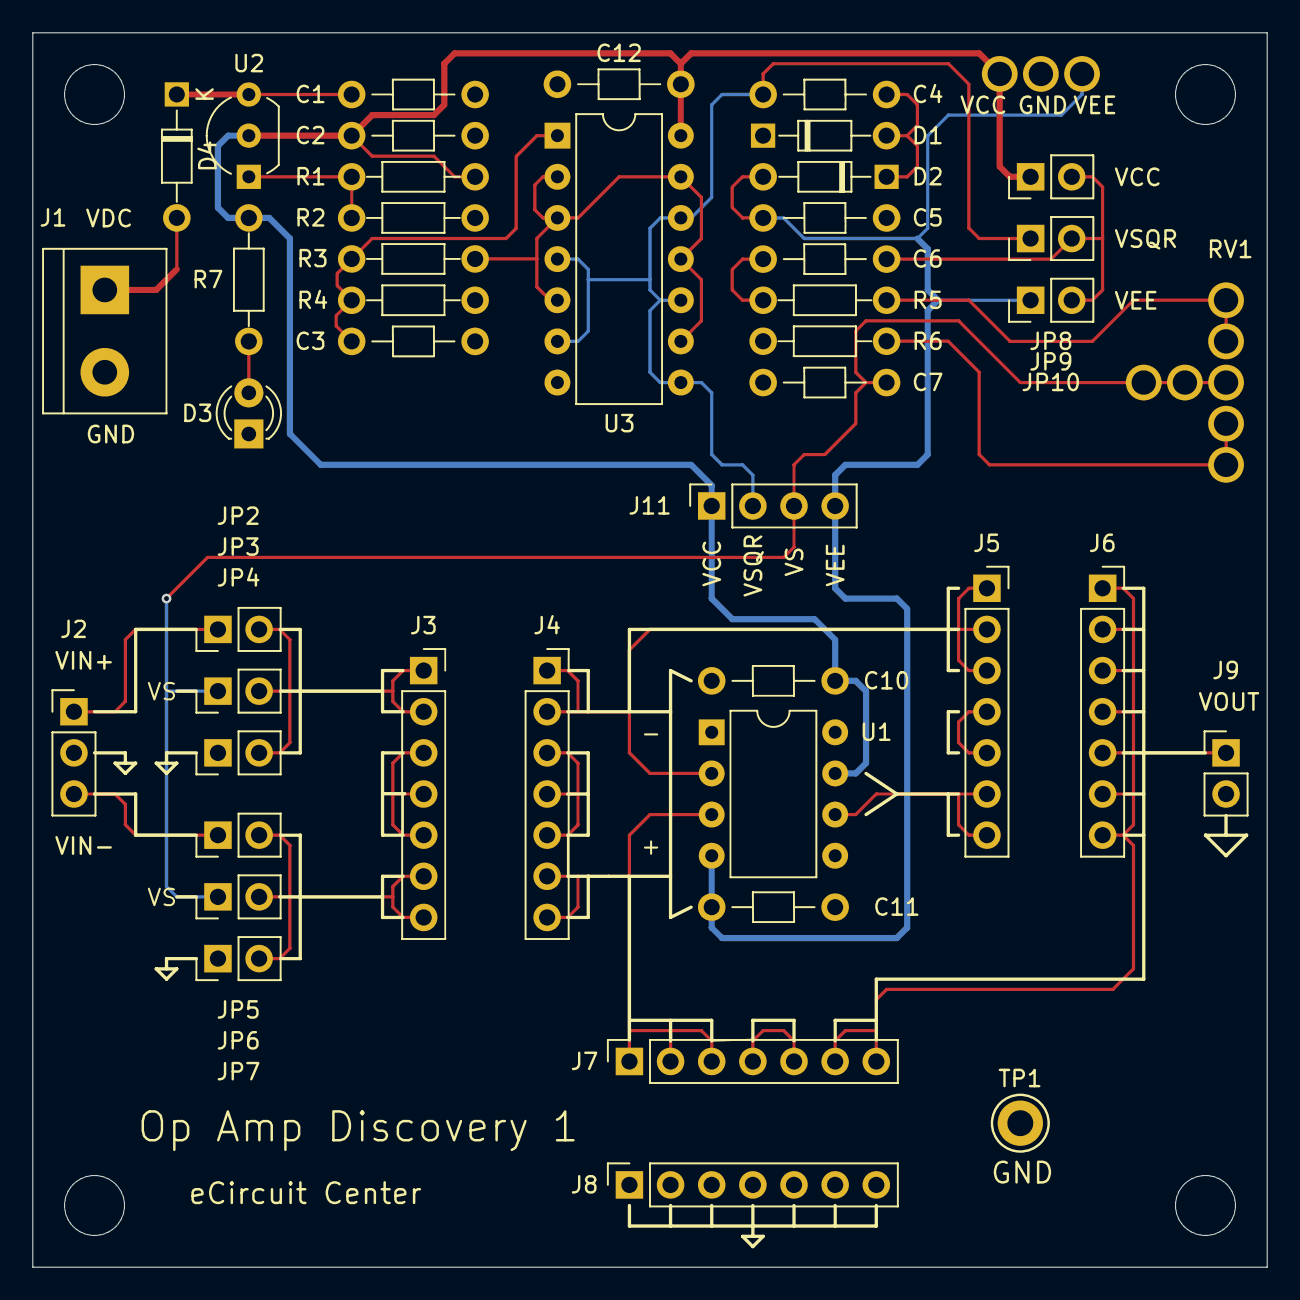
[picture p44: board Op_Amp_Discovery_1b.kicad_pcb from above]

Board: 2 copper layers, 76.2 x 76.2 mm, 58 parts (0 on the bottom side), 28 nets.

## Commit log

2026-01-05 Initial readme and uploads
    Initial readme edit, PDF, KiCAD upload
2026-01-05 Add pcb image
2026-01-08 update users guide, pcb image
2026-01-11 update zip folder, add sch (pdf)
    [Op_Amp_Discovery_1b.kicad_pcb, Op_Amp_Discovery_1b.kicad_sch]
2026-01-15 update users guide, readme
    also remove kiCAD backups
2026-01-20 Add Excel calc, update users guide
    [op-amp-design-calculator-1a.xlsx]
2026-01-23 Update users, example, excel, readme
    [op-amp-design-calculator-1a.xlsx, op-amp-design-calculator-1b.xlsx]
2026-01-23 rename pdfs, edit excel
    [op-amp-design-calculator-1b.xlsx]
